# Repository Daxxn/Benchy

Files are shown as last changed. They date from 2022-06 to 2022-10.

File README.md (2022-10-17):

# BENCHY!!

Your electronics workbench buddy! (Is not actually your buddy, will probably try to kill you, and is hideously expensive.)

## REV1

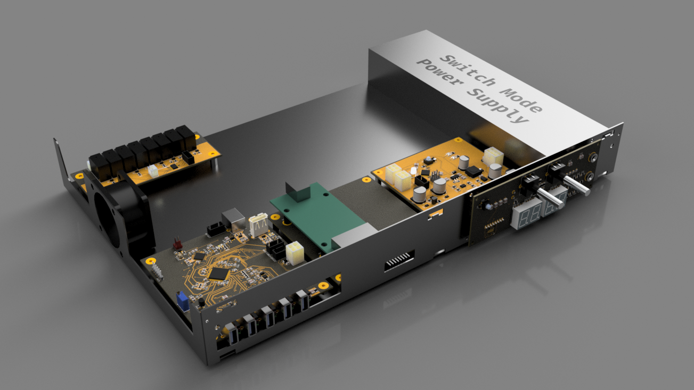
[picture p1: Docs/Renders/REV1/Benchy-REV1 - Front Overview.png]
REV1 Render


## REV2 - Work in Progress

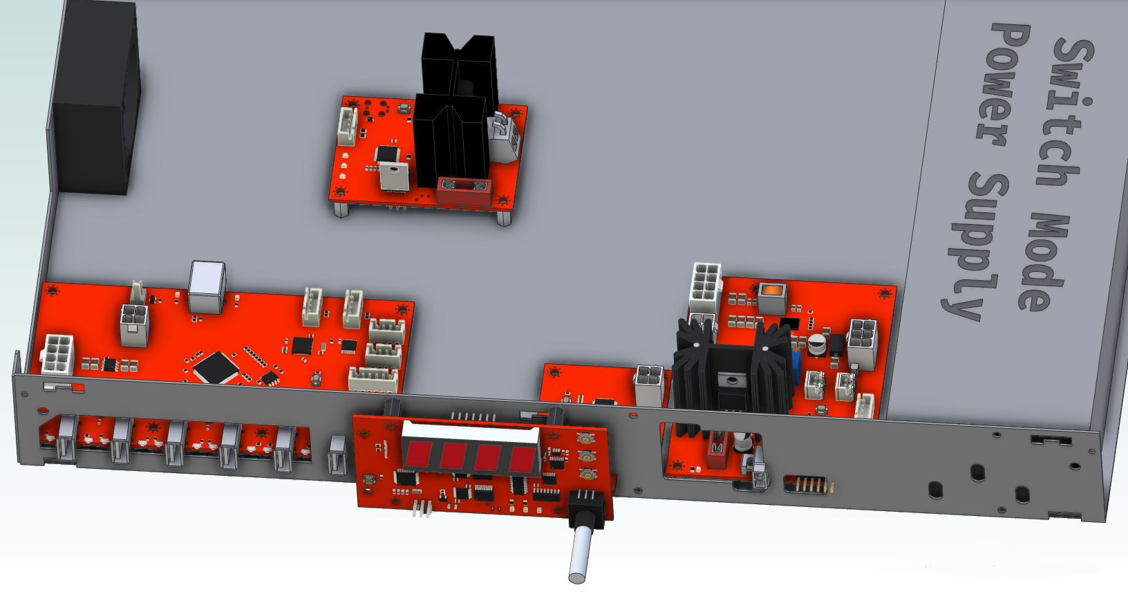
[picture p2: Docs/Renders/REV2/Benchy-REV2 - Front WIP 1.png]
REV2 Render


### Features

- 7 Port USB hub (2.0)
- All data ports are properly protected and able to report per-port current draw
- 5 power-only USB ports
- 8 Software controlled relays for general things like lighting
- Lab power supply capable of 10V @ 2A
- Voltage controlled 30V power supply with over-current protection
- Logic Analyzer
- Electronic load able to sink 5A
- LCR Meter

## I2C Bus

Im using a quite extensive I2C bus system to communicate with the different boards and functional blocks. This cuts WAY down on the number of wires and pins required for the main controller and allows for better modularity within benchy.

Due to the size of the bus and the different devices, the bus is split by an I2C Mux to keep bus integrity while communicating to far PCBs.

## USB Hub

The main reason why I needed to design my own USB hub instead of stuffing an off the shelf hub benchys trumpet was the absolute lack of protection circuitry in most "consumer grade" USB hubs. Theres no back-feed protection, verry little to no current monitoring, and the bare minimum ESD and EMI protection. Thats just not acceptable! imagine my supprise when I cracked open a $85 hub and found a couple controllers and thats it. The cost of finding a hub that has these protections is going to be around the same price as designing and building my own. (Except for the time investment...) Also, these features arent exaclty flashy, they dont look very good on a brochure. So they usually arent there.

The most frustrating part is that these manufacturers _claim_ to conform to the USB spec when the lack protections doesnt.

## Power Supply

The one thing that made the two different power supplies possible was the Switch-Mode Power Supply (SMPS) that was built into the DVR box that spawned this project. The output from the SMPS is a high-current 12V source and a 30V source.

### Adjustable supply

- 30v @ 2A
- Controlled over USB or front panel

The adjustable supply is built with help from [Dave, (Thanks Dave!)](https://www.youtube.com/watch?v=CIGjActDeoM&list=PLBF35875F73B5C9B5&index=1&ab_channel=EEVblog) using the [LM317](https://rocelec.widen.net/view/pdf/mlzstqhekh/slvs044x.pdf?t.download=true&u=5oefqw) adjustable regulator.

### 5V Supply

The [SIC451](https://www.vishay.com/docs/77863/sic450_sic451_sic453.pdf) can supply 25 amps to the USB ports allowing each port to supply around 2 amps. Power is managed by the [UCS2114s.](https://ww1.microchip.com/downloads/aemDocuments/documents/APID/ProductDocuments/DataSheets/UCS2114-Data-Sheet-20005743B.pdf) Controlling both current limit and backfeeding.

## Electronic Load

Fairly standard design using a MOSFET in its linear region, dissipating alot of energy. With the help of a big heatsink and a fan, it can be used to load power supplies or other circuits. The current shunt will allow for precise measurement of power usage. Control is linked to the main microcontroller on the the main board. Allowing for USB control.

## Function generator

Creates sine, square, and triangle waves. from low (100Hz) to medium frequencies (100KHz).

## General Purpose Relays

8 channel relay block used to control general things around benchy.

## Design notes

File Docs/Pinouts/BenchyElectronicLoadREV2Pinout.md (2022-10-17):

# Benchy-ElectronicLoad-REV2

> > Micro: **NANO**
>
> > Digital Pins: **20**
> >
> > Analog Pins: **8**
>
> > Comms:
> > - UART
> > - SPI
> > - I2C

---

## Digital

### Set
Pin Count: 1

| Pin | Name | Type
| --- | --- | --- |
| 6 | I | OUT |

## Analog

### Sense
Pin Count: 2

| Pin | Name | Type
| --- | --- | --- |
| 1 | AI | IN |
| 2 | AV | IN |

## Serial

### UART

### Pins

| Name | Pin |
| --- | --- |
| TX | 1 |
| RX | 0 |

### SPI

### Pins

| Name | Pin |
| --- | --- |
| SCLK | 13 |
| MISO | 12 |
| MOSI | 11 |
| SS | 10 |

### I2C

### Pins

| Name | Pin |
| --- | --- |
| SCLK | 5 |
| SDA | 4 |

> Auto-generated by [PinGenerator app.](https://github.com/Daxxn/PinGenerator)
>
> Author: Daxxn

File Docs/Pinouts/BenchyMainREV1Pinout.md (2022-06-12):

# BenchyMainREV1

> > Micro: **PRO-MICRO**
>
> > Digital Pins: **16**
> >
> > Analog Pins: **4**
>
> > Comms:
> > - SPI
> > - I2C
> > - UART

---

## Digital

### PORT
Pin Count: 5

| Pin | Name | Type
| --- | --- | --- |
| 9 | EN_1 | IN |
| 6 | EN_2 | IN |
| 8 | EN_3 | IN |
| 10 | EN_4 | IN |
| 12 | EN_5 | IN |

### USB
Pin Count: 3

| Pin | Name | Type
| --- | --- | --- |
| 7 | RESET | IN |
| 11 | I2C_EN | IN |

### FAN
Pin Count: 1

| Pin | Name | Type
| --- | --- | --- |
| 13 | CTRL | IN |

## Analog

### PORT
Pin Count: 5

| Pin | Name | Type
| --- | --- | --- |
| 0 | ACURR_1 | IN |
| 1 | ACURR_2 | IN |
| 2 | ACURR_3 | IN |
| 3 | ACURR_4 | IN |
| 4 | ACURR_5 | IN |

### VBUS
Pin Count: 1

| Pin | Name | Type
| --- | --- | --- |
| 5 | ASENSE | IN |

## Serial

### SPI

### Pins

| Name | Pin |
| --- | --- |
| SCK | 15 |
| MISO | 14 |
| MOSI | 16 |

### I2C

### Pins

| Name | Pin |
| --- | --- |
| SDA | 2 |
| SCL | 3 |

### UART

### Pins

| Name | Pin |
| --- | --- |
| TX | 1 |
| RX | 0 |

> Auto-generated by [PinGenerator app.](https://github.com/Daxxn/PinGenerator)
>
> Author: Daxxn

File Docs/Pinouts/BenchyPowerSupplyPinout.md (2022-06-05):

# BenchyPowerSupply

> > Micro: **NANO**
>
> > Digital Pins: **20**
> >
> > Analog Pins: **8**
>
> > Comms:
> > - UART
> > - SPI
> > - I2C

---

## Digital

### Power
Pin Count: 4

| Pin | Name | Type
| --- | --- | --- |
| 2 | OC_SENSE_INT | IN |
| 3 | HIGH_PWM | PWM |
| 5 | LOW_VSET | PWM |
| 6 | LOW_ISET | PWM |

## Analog

### Power
Pin Count: 3

| Pin | Name | Type
| --- | --- | --- |
| 1 | AV30_SENSE | IN |
| 2 | AV12_SENSE | IN |
| 7 | AHIGH_CC_SENSE | IN |

## Serial

### UART

### Pins

| Name | Pin |
| --- | --- |
| TX | 1 |
| RX | 0 |

### SPI

### Pins

| Name | Pin |
| --- | --- |
| SCLK | 13 |
| MISO | 12 |
| MOSI | 11 |
| SS | 10 |

### I2C

### Pins

| Name | Pin |
| --- | --- |
| SCLK | 5 |
| SDA | 4 |

### Addresses

| Name | Pin |
| --- | --- |
| Front | 42 |

> Auto-generated by [PinGenerator app.](https://github.com/Daxxn/PinGenerator)
>
> Author: Daxxn

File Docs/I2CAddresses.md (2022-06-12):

# I2C Bus Addresses

## Main Controller / USB Hub

> Controller (Arduino PRO-MICRO) : MASTER
>
> Front Pannel (PCA9634) : 0x###

## Power Supply

> Controller : 0x11
>
> Front Pannel (Arduino NANO) : 0x12

## Electronic Load

> Controller : 0x21

## Function Generator / LCR Meter

> Controller (Arduino NANO) : 0x31
>
> Front Pannel (PCA9634) : 0x###
>
> LCR Meter (Arduino NANO) : 0x33

## Relays

> IO Expander (PCF8574) : 0x75

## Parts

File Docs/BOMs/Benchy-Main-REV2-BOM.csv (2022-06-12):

Part | Value | Device | Package | Description
C1 | 22pF | C_CHIP-0805(2012-METRIC) | CAPC2012X110 | Capacitor - Generic
C2 | 22pF | C_CHIP-0805(2012-METRIC) | CAPC2012X110 | Capacitor - Generic
C3 | 33pF | C_CHIP-0805(2012-METRIC) | CAPC2012X110 | Capacitor - Generic
C4 | 33pF | C_CHIP-0805(2012-METRIC) | CAPC2012X110 | Capacitor - Generic
C5 | 100nF | C_CHIP-1210(3225-METRIC) | CAPC3225X135 | Capacitor - Generic
C6 | 4.7uF | C_CHIP-0805(2012-METRIC) | CAPC2012X110 | Capacitor - Generic
C7 | 100nF | C_CHIP-0805(2012-METRIC) | CAPC2012X110 | Capacitor - Generic
C8 | 22pF | C_CHIP-0805(2012-METRIC) | CAPC2012X110 | Capacitor - Generic
C9 | 1uF | C_CHIP-0805(2012-METRIC) | CAPC2012X110 | Capacitor - Generic
C10 | 22pF | C_CHIP-0805(2012-METRIC) | CAPC2012X110 | Capacitor - Generic
C11 | 1uF | C_CHIP-0805(2012-METRIC) | CAPC2012X110 | Capacitor - Generic
C12 | 22pF | C_CHIP-0805(2012-METRIC) | CAPC2012X110 | Capacitor - Generic
C13 | 1uF | C_CHIP-0805(2012-METRIC) | CAPC2012X110 | Capacitor - Generic
C14 | 22pF | C_CHIP-0805(2012-METRIC) | CAPC2012X110 | Capacitor - Generic
C15 | 22pF | C_CHIP-0805(2012-METRIC) | CAPC2012X110 | Capacitor - Generic
C16 | 100nF | C_CHIP-0805(2012-METRIC) | CAPC2012X110 | Capacitor - Generic
C17 | 1uF | C_CHIP-0805(2012-METRIC) | CAPC2012X110 | Capacitor - Generic
C18 | 10uF | C_CHIP-0805(2012-METRIC) | CAPC2012X110 | Capacitor - Generic
C19 | 4.7uF | C_CHIP-0805(2012-METRIC) | CAPC2012X110 | Capacitor - Generic
C20 | 22pF | C_CHIP-0805(2012-METRIC) | CAPC2012X110 | Capacitor - Generic
C21 | 100nF | C_CHIP-0805(2012-METRIC) | CAPC2012X110 | Capacitor - Generic
C22 | 1uF | C_CHIP-0805(2012-METRIC) | CAPC2012X110 | Capacitor - Generic
C23 | 22pF | C_CHIP-0805(2012-METRIC) | CAPC2012X110 | Capacitor - Generic
C24 | 1uF | C_CHIP-0805(2012-METRIC) | CAPC2012X110 | Capacitor - Generic
C25 | 22pF | C_CHIP-0805(2012-METRIC) | CAPC2012X110 | Capacitor - Generic
C26 | 22pF | C_CHIP-0805(2012-METRIC) | CAPC2012X110 | Capacitor - Generic
C27 | 22pF | C_CHIP-0805(2012-METRIC) | CAPC2012X110 | Capacitor - Generic
C28 | 22pF | C_CHIP-0805(2012-METRIC) | CAPC2012X110 | Capacitor - Generic
C29 | 22pF | C_CHIP-0805(2012-METRIC) | CAPC2012X110 | Capacitor - Generic
C30 | 22pF | C_CHIP-0805(2012-METRIC) | CAPC2012X110 | Capacitor - Generic
C31 | 22pF | C_CHIP-0805(2012-METRIC) | CAPC2012X110 | Capacitor - Generic
C32 | 22pF | C_CHIP-0805(2012-METRIC) | CAPC2012X110 | Capacitor - Generic
C33 | 22pF | C_CHIP-0805(2012-METRIC) | CAPC2012X110 | Capacitor - Generic
C34 | 4.7uF | C_CHIP-0805(2012-METRIC) | CAPC2012X110 | Capacitor - Generic
C35 | 4.7uF | C_CHIP-0805(2012-METRIC) | CAPC2012X110 | Capacitor - Generic
C36 | 100nF | C_CHIP-0805(2012-METRIC) | CAPC2012X110 | Capacitor - Generic
C37 | 100nF | C_CHIP-0805(2012-METRIC) | CAPC2012X110 | Capacitor - Generic
C38 | 1uF | C_CHIP-0805(2012-METRIC) | CAPC2012X110 | Capacitor - Generic
C39 | 1uF | C_CHIP-0805(2012-METRIC) | CAPC2012X110 | Capacitor - Generic
C40 | 10uF | C_CHIP-0805(2012-METRIC) | CAPC2012X110 | Capacitor - Generic
C41 | 10uF | C_CHIP-0805(2012-METRIC) | CAPC2012X110 | Capacitor - Generic
C42 | 100nF | C_CHIP-0805(2012-METRIC) | CAPC2012X110 | Capacitor - Generic
C43 | 100nF | C_CHIP-0805(2012-METRIC) | CAPC2012X110 | Capacitor - Generic
C44 | 1uF | C_CHIP-1210(3225-METRIC) | CAPC3225X135 | Capacitor - Generic
C46 | 100nF | C_CHIP-1210(3225-METRIC) | CAPC3225X135 | Capacitor - Generic
C47 | 2.2uF | C_CHIP-1210(3225-METRIC) | CAPC3225X135 | Capacitor - Generic
C48 | 1uF | C_CHIP-1210(3225-METRIC) | CAPC3225X135 | Capacitor - Generic
C49 | 1uF | C_CHIP-1210(3225-METRIC) | CAPC3225X135 | Capacitor - Generic
C50 | 120uF | C-POL_TANTALUM-2917(7343-METRIC) | CAPMP7343X310N | Capacitor Polarised - Generic
C51 | 120uF | C-POL_TANTALUM-2917(7343-METRIC) | CAPMP7343X310N | Capacitor Polarised - Generic
C52 | 120uF | C-POL_TANTALUM-2917(7343-METRIC) | CAPMP7343X310N | Capacitor Polarised - Generic
C53 | 120uF | C-POL_TANTALUM-2917(7343-METRIC) | CAPMP7343X310N | Capacitor Polarised - Generic
C54 | 120uF | C-POL_TANTALUM-2917(7343-METRIC) | CAPMP7343X310N | Capacitor Polarised - Generic
C55 | 120uF | C-POL_TANTALUM-2917(7343-METRIC) | CAPMP7343X310N | Capacitor Polarised - Generic
C56 | 100nF | C_CHIP-0805(2012-METRIC) | CAPC2012X110 | Capacitor - Generic
C57 | 100nF | C_CHIP-0805(2012-METRIC) | CAPC2012X110 | Capacitor - Generic
C58 | 1uF | C_CHIP-0805(2012-METRIC) | CAPC2012X110 | Capacitor - Generic
C59 | 100nF | C_CHIP-1210(3225-METRIC) | CAPC3225X135 | Capacitor - Generic
D1 | 1N4448WS | 1N4448WS | SOD2412X120N | Small Signal Diode
D2 | 1N4448WS | 1N4448WS | SOD2412X120N | Small Signal Diode
D3 | 1N4448WS | 1N4448WS | SOD2412X120N | Small Signal Diode
D4 | 1N4448WS | 1N4448WS | SOD2412X120N | Small Signal Diode
D5 | 1N4448WS | 1N4448WS | SOD2412X120N | Small Signal Diode
D6 | GREEN | CHIP-ROUND-G_0805 | LEDC2012X105N_RND-G
D7 | GREEN | CHIP-ROUND-G_0805 | LEDC2012X105N_RND-G
D8 | WP4060VH/IGD | WP4060VH/IGD | WP4060VH
D9 | WP4060VH/IGD | WP4060VH/IGD | WP4060VH
D10 | WP4060VH/IGD | WP4060VH/IGD | WP4060VH
D11 | WP4060VH/IGD | WP4060VH/IGD | WP4060VH
D12 | WP4060VH/IGD | WP4060VH/IGD | WP4060VH
D13 | SS14-CHAN | SS14-CHAN | SS14-CHAN | SMD Schottky
D15 | YELLOW | CHIP-ROUND-Y_0805 | LEDC2012X105N_RND-Y
D16 | YELLOW | CHIP-ROUND-Y_0805 | LEDC2012X105N_RND-Y
ICSP | PINHD-1X6 | PINHD-1X6 | 1X06 | PIN HEADER
J-FRONT-COM | 690367290476 | 690367290476 | 690367290476
J-FUNC-COM | B4B-XH-A | B4B-XH-A | JST-XH-4
J-LOGA-USB | 1734366 | 1734366 | 1734366 | USB(2.0) Type-A, RCPT, 4POS, THT-VERT
J-PS-COM | B4B-XH-A | B4B-XH-A | JST-XH-4
J-RELAY-COM | B4B-XH-A | B4B-XH-A | JST-XH-4
J-USB-OUT | USB-B1HSB6 | USB-B1HSB6 | USB-B1HSB6
J1 | 640456-2 | 640456-2 | 640456-2
J2 | MOLEX-4 | MOLEX-4 | MOLEX-4
L1 | 4.7uH | L_CHIP-1206(3216-METRIC) | INDC3216X190 | Inductor Fixed - Generic
MP1 | STANDOFF_F/F_M2.5_5MM | STANDOFF_F/F_M2.5_5MM | STANDOFF_HEX_FEMALE_500X500_M2.5X0.45_MTGP755H270 | Female-Female Standoff/Spacer with Mounting pad and hole.
MP2 | STANDOFF_F/F_M2.5_5MM | STANDOFF_F/F_M2.5_5MM | STANDOFF_HEX_FEMALE_500X500_M2.5X0.45_MTGP755H270 | Female-Female Standoff/Spacer with Mounting pad and hole.
MP3 | STANDOFF_F/F_M2.5_5MM | STANDOFF_F/F_M2.5_5MM | STANDOFF_HEX_FEMALE_500X500_M2.5X0.45_MTGP755H270 | Female-Female Standoff/Spacer with Mounting pad and hole.
MP4 | STANDOFF_F/F_M2.5_5MM | STANDOFF_F/F_M2.5_5MM | STANDOFF_HEX_FEMALE_500X500_M2.5X0.45_MTGP755H270 | Female-Female Standoff/Spacer with Mounting pad and hole.
P2 | 50KΩ | 3296W | 3296W
Q1 | SQ2310ES | SQ2310ES | SOT-23-3_-_SOT95P280X100-3N | N-Ch MOSFET
Q2 | CPH3348-TL-W | CPH3348-TL-W | SOT-23-3_-_SOT95P280X100-3N | -12V P-Ch MOSFET
Q3 | CPH3348-TL-W | CPH3348-TL-W | SOT-23-3_-_SOT95P280X100-3N | -12V P-Ch MOSFET
Q4 | BC807 | BC807 | SOT-23-3_-_SOT95P280X100-3N | PNP 45V Transistor
Q5 | BC807 | BC807 | SOT-23-3_-_SOT95P280X100-3N | PNP 45V Transistor
Q6 | BC807 | BC807 | SOT-23-3_-_SOT95P280X100-3N | PNP 45V Transistor
Q7 | BC807 | BC807 | SOT-23-3_-_SOT95P280X100-3N | PNP 45V Transistor
Q8 | CPH3348-TL-W | CPH3348-TL-W | SOT-23-3_-_SOT95P280X100-3N | -12V P-Ch MOSFET
Q9 | BC807 | BC807 | SOT-23-3_-_SOT95P280X100-3N | PNP 45V Transistor
Q10 | BC807 | BC807 | SOT-23-3_-_SOT95P280X100-3N | PNP 45V Transistor
Q11 | CPH3348-TL-W | CPH3348-TL-W | SOT-23-3_-_SOT95P280X100-3N | -12V P-Ch MOSFET
Q12 | BC807 | BC807 | SOT-23-3_-_SOT95P280X100-3N | PNP 45V Transistor
Q13 | BC807 | BC807 | SOT-23-3_-_SOT95P280X100-3N | PNP 45V Transistor
Q14 | CPH3348-TL-W | CPH3348-TL-W | SOT-23-3_-_SOT95P280X100-3N | -12V P-Ch MOSFET
Q15 | BC807 | BC807 | SOT-23-3_-_SOT95P280X100-3N | PNP 45V Transistor
Q16 | BC807 | BC807 | SOT-23-3_-_SOT95P280X100-3N | PNP 45V Transistor
Q17 | DMG2301L | DMG2301L | SOT-23-3_-_SOT95P280X100-3N
Q18 | DMG2301L | DMG2301L | SOT-23-3_-_SOT95P280X100-3N
Q19 | DMG2301L | DMG2301L | SOT-23-3_-_SOT95P280X100-3N
Q20 | DMG2301L | DMG2301L | SOT-23-3_-_SOT95P280X100-3N
Q21 | DMG2301L | DMG2301L | SOT-23-3_-_SOT95P280X100-3N
R1 | 100Ω | R-US_CHIP-0805(2012-METRIC) | RESC2012X65 | Resistor Fixed - ANSI
R2 | 10KΩ | R-US_CHIP-0805(2012-METRIC) | RESC2012X65 | Resistor Fixed - ANSI
R3 | 100KΩ | R-US_CHIP-1206(3216-METRIC) | RESC3216X70 | Resistor Fixed - ANSI
R4 | 100KΩ | R-US_CHIP-1206(3216-METRIC) | RESC3216X70 | Resistor Fixed - ANSI
R5 | 100KΩ | R-US_CHIP-1206(3216-METRIC) | RESC3216X70 | Resistor Fixed - ANSI
R6 | 100KΩ | R-US_CHIP-1206(3216-METRIC) | RESC3216X70 | Resistor Fixed - ANSI
R7 | 100KΩ | R-US_CHIP-1206(3216-METRIC) | RESC3216X70 | Resistor Fixed - ANSI
R8 | 100KΩ | R-US_CHIP-1206(3216-METRIC) | RESC3216X70 | Resistor Fixed - ANSI
R9 | 100KΩ | R-US_CHIP-1206(3216-METRIC) | RESC3216X70 | Resistor Fixed - ANSI
R10 | 100KΩ | R-US_CHIP-1206(3216-METRIC) | RESC3216X70 | Resistor Fixed - ANSI
R11 | 10KΩ | R-US_CHIP-1206(3216-METRIC) | RESC3216X70 | Resistor Fixed - ANSI
R12 | 100KΩ | R-US_CHIP-1206(3216-METRIC) | RESC3216X70 | Resistor Fixed - ANSI
R13 | 100KΩ | R-US_CHIP-1206(3216-METRIC) | RESC3216X70 | Resistor Fixed - ANSI
R14 | 150mΩ | R-US_CHIP-2010(5025-METRIC) | RESC5025X71 | Resistor Fixed - ANSI
R15 | 150mΩ | R-US_CHIP-2010(5025-METRIC) | RESC5025X71 | Resistor Fixed - ANSI
R16 | 150mΩ | R-US_CHIP-2010(5025-METRIC) | RESC5025X71 | Resistor Fixed - ANSI
R17 | 150mΩ | R-US_CHIP-2010(5025-METRIC) | RESC5025X71 | Resistor Fixed - ANSI
R18 | 150mΩ | R-US_CHIP-2010(5025-METRIC) | RESC5025X71 | Resistor Fixed - ANSI
R19 | 27Ω | R-US_CHIP-0805(2012-METRIC) | RESC2012X65 | Resistor Fixed - ANSI
R20 | 27Ω | R-US_CHIP-0805(2012-METRIC) | RESC2012X65 | Resistor Fixed - ANSI
R21 | 27Ω | R-US_CHIP-0805(2012-METRIC) | RESC2012X65 | Resistor Fixed - ANSI
R22 | 27Ω | R-US_CHIP-0805(2012-METRIC) | RESC2012X65 | Resistor Fixed - ANSI
R23 | 27Ω | R-US_CHIP-0805(2012-METRIC) | RESC2012X65 | Resistor Fixed - ANSI
R24 | 27Ω | R-US_CHIP-0805(2012-METRIC) | RESC2012X65 | Resistor Fixed - ANSI
R25 | 1MΩ | R-US_CHIP-0805(2012-METRIC) | RESC2012X65 | Resistor Fixed - ANSI
R26 | 10KΩ | R-US_CHIP-0805(2012-METRIC) | RESC2012X65 | Resistor Fixed - ANSI
R27 | 100KΩ | R-US_CHIP-0805(2012-METRIC) | RESC2012X65 | Resistor Fixed - ANSI
R28 | 100Ω | R-US_CHIP-0805(2012-METRIC) | RESC2012X65 | Resistor Fixed - ANSI
R29 | 100Ω | R-US_CHIP-0805(2012-METRIC) | RESC2012X65 | Resistor Fixed - ANSI
R30 | 100Ω | R-US_CHIP-0805(2012-METRIC) | RESC2012X65 | Resistor Fixed - ANSI
R31 | 100Ω | R-US_CHIP-0805(2012-METRIC) | RESC2012X65 | Resistor Fixed - ANSI
R32 | 100Ω | R-US_CHIP-0805(2012-METRIC) | RESC2012X65 | Resistor Fixed - ANSI
R33 | 10KΩ | R-US_CHIP-0805(2012-METRIC) | RESC2012X65 | Resistor Fixed - ANSI
R34 | 10KΩ | R-US_CHIP-0805(2012-METRIC) | RESC2012X65 | Resistor Fixed - ANSI
R35 | 10KΩ | R-US_CHIP-0805(2012-METRIC) | RESC2012X65 | Resistor Fixed - ANSI
R36 | 10KΩ | R-US_CHIP-0805(2012-METRIC) | RESC2012X65 | Resistor Fixed - ANSI
R37 | 10KΩ | R-US_CHIP-0805(2012-METRIC) | RESC2012X65 | Resistor Fixed - ANSI
R38 | 27Ω | R-US_CHIP-0805(2012-METRIC) | RESC2012X65 | Resistor Fixed - ANSI
R39 | 27Ω | R-US_CHIP-0805(2012-METRIC) | RESC2012X65 | Resistor Fixed - ANSI
R40 | 27Ω | R-US_CHIP-0805(2012-METRIC) | RESC2012X65 | Resistor Fixed - ANSI
R41 | 27Ω | R-US_CHIP-0805(2012-METRIC) | RESC2012X65 | Resistor Fixed - ANSI
R42 | 27Ω | R-US_CHIP-0805(2012-METRIC) | RESC2012X65 | Resistor Fixed - ANSI
R43 | 27Ω | R-US_CHIP-0805(2012-METRIC) | RESC2012X65 | Resistor Fixed - ANSI
R44 | 27Ω | R-US_CHIP-0805(2012-METRIC) | RESC2012X65 | Resistor Fixed - ANSI
R45 | 27Ω | R-US_CHIP-0805(2012-METRIC) | RESC2012X65 | Resistor Fixed - ANSI
R46 | 27Ω | R-US_CHIP-0805(2012-METRIC) | RESC2012X65 | Resistor Fixed - ANSI
R47 | 27Ω | R-US_CHIP-0805(2012-METRIC) | RESC2012X65 | Resistor Fixed - ANSI
R48 | 15KΩ | R-US_CHIP-0805(2012-METRIC) | RESC2012X65 | Resistor Fixed - ANSI
R49 | 15KΩ | R-US_CHIP-0805(2012-METRIC) | RESC2012X65 | Resistor Fixed - ANSI
R50 | 15KΩ | R-US_CHIP-0805(2012-METRIC) | RESC2012X65 | Resistor Fixed - ANSI
R51 | 15KΩ | R-US_CHIP-0805(2012-METRIC) | RESC2012X65 | Resistor Fixed - ANSI
R52 | 15KΩ | R-US_CHIP-0805(2012-METRIC) | RESC2012X65 | Resistor Fixed - ANSI
R53 | 15KΩ | R-US_CHIP-0805(2012-METRIC) | RESC2012X65 | Resistor Fixed - ANSI
R54 | 15KΩ | R-US_CHIP-0805(2012-METRIC) | RESC2012X65 | Resistor Fixed - ANSI
R55 | 15KΩ | R-US_CHIP-0805(2012-METRIC) | RESC2012X65 | Resistor Fixed - ANSI
R56 | 15KΩ | R-US_CHIP-0805(2012-METRIC) | RESC2012X65 | Resistor Fixed - ANSI
R57 | 15KΩ | R-US_CHIP-0805(2012-METRIC) | RESC2012X65 | Resistor Fixed - ANSI
R58 | 15KΩ | R-US_CHIP-0805(2012-METRIC) | RESC2012X65 | Resistor Fixed - ANSI
R59 | 15KΩ | R-US_CHIP-0805(2012-METRIC) | RESC2012X65 | Resistor Fixed - ANSI
R60 | 15KΩ | R-US_CHIP-0805(2012-METRIC) | RESC2012X65 | Resistor Fixed - ANSI
R61 | 15KΩ | R-US_CHIP-0805(2012-METRIC) | RESC2012X65 | Resistor Fixed - ANSI
R62 | 15KΩ | R-US_CHIP-0805(2012-METRIC) | RESC2012X65 | Resistor Fixed - ANSI
R63 | 15KΩ | R-US_CHIP-0805(2012-METRIC) | RESC2012X65 | Resistor Fixed - ANSI
R64 | 4.7KΩ | R-US_CHIP-0805(2012-METRIC) | RESC2012X65 | Resistor Fixed - ANSI
R65 | 4.7KΩ | R-US_CHIP-0805(2012-METRIC) | RESC2012X65 | Resistor Fixed - ANSI
R66 | 12KΩ | R-US_CHIP-0805(2012-METRIC) | RESC2012X65 | Resistor Fixed - ANSI
R67 | 330Ω | R-US_CHIP-0805(2012-METRIC) | RESC2012X65 | Resistor Fixed - ANSI
R68 | 330Ω | R-US_CHIP-0805(2012-METRIC) | RESC2012X65 | Resistor Fixed - ANSI
R69 | 330Ω | R-US_CHIP-0805(2012-METRIC) | RESC2012X65 | Resistor Fixed - ANSI
R70 | 330Ω | R-US_CHIP-0805(2012-METRIC) | RESC2012X65 | Resistor Fixed - ANSI
R71 | 330Ω | R-US_CHIP-0805(2012-METRIC) | RESC2012X65 | Resistor Fixed - ANSI
R72 | 330Ω | R-US_CHIP-0805(2012-METRIC) | RESC2012X65 | Resistor Fixed - ANSI
R73 | 330Ω | R-US_CHIP-0805(2012-METRIC) | RESC2012X65 | Resistor Fixed - ANSI
R74 | 330Ω | R-US_CHIP-0805(2012-METRIC) | RESC2012X65 | Resistor Fixed - ANSI
R75 | 330Ω | R-US_CHIP-0805(2012-METRIC) | RESC2012X65 | Resistor Fixed - ANSI
R76 | 330Ω | R-US_CHIP-0805(2012-METRIC) | RESC2012X65 | Resistor Fixed - ANSI
R77 | 10KΩ | R-US_CHIP-0805(2012-METRIC) | RESC2012X65 | Resistor Fixed - ANSI
R78 | 10KΩ | R-US_CHIP-0805(2012-METRIC) | RESC2012X65 | Resistor Fixed - ANSI
R79 | 100KΩ | R-US_CHIP-0805(2012-METRIC) | RESC2012X65 | Resistor Fixed - ANSI
R80 | 330Ω | R-US_CHIP-0805(2012-METRIC) | RESC2012X65 | Resistor Fixed - ANSI
R81 | 330Ω | R-US_CHIP-0805(2012-METRIC) | RESC2012X65 | Resistor Fixed - ANSI
R82 | 1KΩ | R-US_CHIP-0805(2012-METRIC) | RESC2012X65 | Resistor Fixed - ANSI
R83 | 3.3KΩ | R-US_CHIP-0805(2012-METRIC) | RESC2012X65 | Resistor Fixed - ANSI
R84 | 1KΩ | R-US_CHIP-0805(2012-METRIC) | RESC2012X65 | Resistor Fixed - ANSI
R85 | 1KΩ | R-US_CHIP-0805(2012-METRIC) | RESC2012X65 | Resistor Fixed - ANSI
R86 | 1KΩ | R-US_CHIP-0805(2012-METRIC) | RESC2012X65 | Resistor Fixed - ANSI
R87 | 1KΩ | R-US_CHIP-0805(2012-METRIC) | RESC2012X65 | Resistor Fixed - ANSI
R88 | 1KΩ | R-US_CHIP-0805(2012-METRIC) | RESC2012X65 | Resistor Fixed - ANSI
R89 | 1KΩ | R-US_CHIP-0805(2012-METRIC) | RESC2012X65 | Resistor Fixed - ANSI
R90 | 330Ω | R-US_CHIP-0805(2012-METRIC) | RESC2012X65 | Resistor Fixed - ANSI
R91 | 330Ω | R-US_CHIP-0805(2012-METRIC) | RESC2012X65 | Resistor Fixed - ANSI
R92 | 330Ω | R-US_CHIP-1206(3216-METRIC) | RESC3216X70 | Resistor Fixed - ANSI
R93 | 100KΩ | R-US_CHIP-0805(2012-METRIC) | RESC2012X65 | Resistor Fixed - ANSI
R94 | 1.5KΩ | R-US_CHIP-0805(2012-METRIC) | RESC2012X65 | Resistor Fixed - ANSI
R95 | 1.5KΩ | R-US_CHIP-0805(2012-METRIC) | RESC2012X65 | Resistor Fixed - ANSI
R96 | 1.5KΩ | R-US_CHIP-0805(2012-METRIC) | RESC2012X65 | Resistor Fixed - ANSI
R97 | 1.5KΩ | R-US_CHIP-0805(2012-METRIC) | RESC2012X65 | Resistor Fixed - ANSI
R98 | 1.5KΩ | R-US_CHIP-0805(2012-METRIC) | RESC2012X65 | Resistor Fixed - ANSI
R99 | 50KΩ | R-US_CHIP-0805(2012-METRIC) | RESC2012X65 | Resistor Fixed - ANSI
R100 | 50KΩ | R-US_CHIP-0805(2012-METRIC) | RESC2012X65 | Resistor Fixed - ANSI
RESET | TL3365 | TL3365 | TL3365
RV1 | VC1206 | VARISTOR_VC1206_CHIP-1206 | VARC3216X102N | Varistor - Popular parts
RV2 | VC1206 | VARISTOR_VC1206_CHIP-1206 | VARC3216X102N | Varistor - Popular parts
RV3 | VC1206 | VARISTOR_VC1206_CHIP-1206 | VARC3216X102N | Varistor - Popular parts
RV4 | VC1206 | VARISTOR_VC1206_CHIP-1206 | VARC3216X102N | Varistor - Popular parts
RV5 | VC1206 | VARISTOR_VC1206_CHIP-1206 | VARC3216X102N | Varistor - Popular parts
TVS1 | D5V0L2B3SO | D5V0L2B3SO | SOT23-3_-_SOT95P240X110-3N
TVS3 | D5V0L2B3SO | D5V0L2B3SO | SOT23-3_-_SOT95P240X110-3N
TVS4 | D5V0L2B3SO | D5V0L2B3SO | SOT23-3_-_SOT95P240X110-3N
TVS6 | D5V0L2B3SO | D5V0L2B3SO | SOT23-3_-_SOT95P240X110-3N
TVS8 | D5V0L2B3SO | D5V0L2B3SO | SOT23-3_-_SOT95P240X110-3N
TVS10 | D5V0L2B3SO | D5V0L2B3SO | SOT23-3_-_SOT95P240X110-3N
TVS12 | D5V0L2B3SO | D5V0L2B3SO | SOT23-3_-_SOT95P240X110-3N
U1 | INA4180A4IPWRHS-TSSOP-14 | INA4180A4IPWRHS-TSSOP-14 | HS-TSSOP-14 | 4 Ch Current Shunt Amplifier
U2 | INA181A-X | INA181A-X | SOT-23-6PIN | Single Current Shunt Amplifier
U3 | ATMEGA-32U4 | ATMEGA-32U4 | QFN-44_-_QFN50P700X700X100-45T500N | Stand Alone - Ardunio Pro Micro
U4 | USB2507 | USB2507 | TQFP-80_-_QFP50P1400X1400X120-80N | USB 2.0 7-Port Hub Controller
U6 | PCA9515HS-SO-8 | PCA9515HS-SO-8 | SOIC127P600X175-8N__HS__AS5600 | I2C Bus Repeater
U7 | 24CXXSOIC-8 | 24CXXSOIC-8 | SOIC127P600X175-8N__AS5600
U8 | TSX339-HS-TSSOP-14 | TSX339-HS-TSSOP-14 | TSSOP-14-HS_-_SOP65P640X120-14N | sub {
U12 | TLV7021-SOT23-5 | TLV7021-SOT23-5 | SOT23-5_-_SOT95P280X145-5N | sub {
U13 | SN74LV08 | SN74LV08 | SOIC-14_-_SOIC127P600X175-14N | Quad AND Gates 2-Input
U15 | CD4011 | CD4011 | TSSOP-14_-_SOP65P640X120-14N | Quad NAND Gates 2-Input
U17 | TLV9151-HS | TLV9151-HS | SOT23-5-HS_-_SOT95P280X145-5N | sub {
U19 | 74HC2G08 | 74HC2G08 | TSSOP-8_-_SOP65P400X110-8N | Dual AND Gates 2-Input
U20 | SN74LVC1G06 | SN74LVC1G06 | SOT23-5_-_SOT95P275X145-5N
USB-1 | USB-A-SIDE | USB-A-SIDE | USB-A-SIDE
USB-2 | USB-A-SIDE | USB-A-SIDE | USB-A-SIDE
USB-3 | USB-A-SIDE | USB-A-SIDE | USB-A-SIDE
USB-4 | USB-A-SIDE | USB-A-SIDE | USB-A-SIDE
USB-5 | USB-A-SIDE | USB-A-SIDE | USB-A-SIDE
VR1 | TL1431TO-92 | TL1431TO-92 | TO-92 | Precision Adjustable Voltage Reference
X1 | ECS-240-10-37B2-JTN | ECS-240-10-37B2-JTN | SMD-OSC-2X1_6_-_OSCCC200X160X50N | 2X1.6 Crystal Oscillator
X4 | 16MHz | RH100-16-8-1010 | OSC-1010_-_OSCCC320X250X69N | Crystal Oscillator SMD

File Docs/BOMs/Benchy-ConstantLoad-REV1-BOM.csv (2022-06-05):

Part | Value | Device | Package | Description
C1 | 100nF | C_CHIP-0805(2012-METRIC) | CAPC2012X110 | Capacitor - Generic
C2 | 100nF | C_CHIP-0805(2012-METRIC) | CAPC2012X110 | Capacitor - Generic
C3 | 100nF | C_CHIP-0805(2012-METRIC) | CAPC2012X110 | Capacitor - Generic
C4 | 100nF | C_CHIP-0805(2012-METRIC) | CAPC2012X110 | Capacitor - Generic
C5 | 100nF | C_CHIP-0805(2012-METRIC) | CAPC2012X110 | Capacitor - Generic
C6 | 1uF | C_CHIP-0805(2012-METRIC) | CAPC2012X110 | Capacitor - Generic
C7 | 100nF | C_CHIP-0805(2012-METRIC) | CAPC2012X110 | Capacitor - Generic
C8 | 47uF | C_CHIP-0805(2012-METRIC) | CAPC2012X110 | Capacitor - Generic
C9 | 100nF | C_CHIP-0805(2012-METRIC) | CAPC2012X110 | Capacitor - Generic
C10 | 100nF | C_CHIP-0805(2012-METRIC) | CAPC2012X110 | Capacitor - Generic
C11 | 100nF | C_CHIP-0805(2012-METRIC) | CAPC2012X110 | Capacitor - Generic
D1 | LSM115JE3 | LSM115JE3 | DO-214BA_-_DIOM4336X330N | sub {
ICSP1 | ICSP-TAG-CONN | ICSP-TAG-CONN | TAG-CONN
J-FRONT-COM | B4B-XH-A-REV2 | B4B-XH-A-REV2 | JST-XH-4
J-MAIN-COM | B4B-XH-A-REV2 | B4B-XH-A-REV2 | JST-XH-4
J-PWR | B2B-XH-A-REV2 | B2B-XH-A-REV2 | JST-XH-2
J1 | 2834082-1 | 2834082-1 | 2834082-1
MP1 | STANDOFF_F/F_M3_10MM | STANDOFF_F/F_M3_10MM | STANDOFF_HEX_FEMALE_550X1000_M3X0.5_MTGP850H320 | Female-Female Standoff/Spacer with Mounting pad and hole.
MP2 | STANDOFF_F/F_M3_10MM | STANDOFF_F/F_M3_10MM | STANDOFF_HEX_FEMALE_550X1000_M3X0.5_MTGP850H320 | Female-Female Standoff/Spacer with Mounting pad and hole.
MP3 | STANDOFF_F/F_M3_10MM | STANDOFF_F/F_M3_10MM | STANDOFF_HEX_FEMALE_550X1000_M3X0.5_MTGP850H320 | Female-Female Standoff/Spacer with Mounting pad and hole.
MP4 | STANDOFF_F/F_M3_10MM | STANDOFF_F/F_M3_10MM | STANDOFF_HEX_FEMALE_550X1000_M3X0.5_MTGP850H320 | Female-Female Standoff/Spacer with Mounting pad and hole.
P1 | 10K | 3296W | 3296W
Q2 | IRF840-HSHS | IRF840-HSHS | TO-220-VERT-HS | sub {
R1 | 10K | R-US_CHIP-0805(2012-METRIC) | RESC2012X65 | Resistor Fixed - ANSI
R2 | 10K | R-US_CHIP-0805(2012-METRIC) | RESC2012X65 | Resistor Fixed - ANSI
R3 | 10 | R-US_CHIP-0805(2012-METRIC) | RESC2012X65 | Resistor Fixed - ANSI
R4 | 1K | R-US_CHIP-0805(2012-METRIC) | RESC2012X65 | Resistor Fixed - ANSI
R5 | 4.7k | R-US_CHIP-0805(2012-METRIC) | RESC2012X65 | Resistor Fixed - ANSI
R6 | 4.7k | R-US_CHIP-0805(2012-METRIC) | RESC2012X65 | Resistor Fixed - ANSI
R7 | 4.7K | R-US_CHIP-0805(2012-METRIC) | RESC2012X65 | Resistor Fixed - ANSI
R8 | 10K | R-US_CHIP-0805(2012-METRIC) | RESC2012X65 | Resistor Fixed - ANSI
R9 | 10K | R-US_CHIP-0805(2012-METRIC) | RESC2012X65 | Resistor Fixed - ANSI
RESET | TL3365 | TL3365 | TL3365
RS1 | 14AFR010E | 14AFR010E | RESAD2182W66L1845D630B | High Power Shunt Resistor
U1 | ATMEGA-328PHS | ATMEGA-328PHS | QFP-32-HS_-_QFP80P900X900X120-33T500N | Stand Alone - Arduino Nano
U2 | ZXGD3009E6NORM | ZXGD3009E6NORM | SOT-23-6PIN
U3 | INA181A-X | INA181A-X | SOT-23-6PIN | Single Current Shunt Amplifier
U4 | TLV7021-SOT23-5 | TLV7021-SOT23-5 | SOT23-5_-_SOT95P280X145-5N | Low Power 5V Comparator
X1 | CSTCE16M0V53-R0SMD | CSTCE16M0V53-R0SMD | CSTCE16M0V53-R0 | SMD Resonator from the Arduino NANO

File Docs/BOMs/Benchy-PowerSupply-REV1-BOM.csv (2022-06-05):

Part | Value | Device | Package | Description
C1 | 100uF | C-POL_ECAP-10.5MM | CAPAE1030X1050N | Capacitor Polarised - Generic
C2 | 100nF | C_CHIP-0805(2012-METRIC) | CAPC2012X110 | Capacitor - Generic
C3 | 10uF | C_CHIP-1210(3225-METRIC) | CAPC3225X135 | Capacitor - Generic
C4 | 0.1uF | C_CHIP-1210(3225-METRIC) | CAPC3225X135 | Capacitor - Generic
C5 | 4.7nF | C_CHIP-1210(3225-METRIC) | CAPC3225X135 | Capacitor - Generic
C6 | 0.1uF | C_CHIP-1210(3225-METRIC) | CAPC3225X135 | Capacitor - Generic
C7 | 10uF | C_CHIP-1210(3225-METRIC) | CAPC3225X135 | Capacitor - Generic
C8 | 100uF | C-POL_ECAP-8.5MM | CAPAE830X1050N | Capacitor Polarised - Generic
C9 | 100nF | C_CHIP-1206(3216-METRIC) | CAPC3216X135 | Capacitor - Generic
C10 | 10uF | C-POL_TANTALUM-1206(3216-METRIC) | CAPMP3216X180N | Capacitor Polarised - Generic
C11 | 1uF | C_CHIP-1210(3225-METRIC) | CAPC3225X135 | Capacitor - Generic
C12 | 0.1uF | C_CHIP-1210(3225-METRIC) | CAPC3225X135 | Capacitor - Generic
C13 | 10uF | C_CHIP-1210(3225-METRIC) | CAPC3225X135 | Capacitor - Generic
C14 | 4.7uF | C_CHIP-1210(3225-METRIC) | CAPC3225X135 | Capacitor - Generic
C15 | 4.7uF | C_CHIP-1210(3225-METRIC) | CAPC3225X135 | Capacitor - Generic
C16 | 100nF | C_CHIP-0805(2012-METRIC) | CAPC2012X110 | Capacitor - Generic
C17 | 22nF | C_CHIP-1210(3225-METRIC) | CAPC3225X135 | Capacitor - Generic
C18 | 22nF | C_CHIP-1210(3225-METRIC) | CAPC3225X135 | Capacitor - Generic
C19 | 100nF | C_CHIP-1210(3225-METRIC) | CAPC3225X135 | Capacitor - Generic
C20 | 1uF | C_CHIP-1210(3225-METRIC) | CAPC3225X135 | Capacitor - Generic
C21 | 1uF | C_CHIP-1210(3225-METRIC) | CAPC3225X135 | Capacitor - Generic
C22 | 100nF | C_CHIP-1210(3225-METRIC) | CAPC3225X135 | Capacitor - Generic
C23 | 47uF | C-POL_TANTALUM-1206(3216-METRIC) | CAPMP3216X180N | Capacitor Polarised - Generic
C24 | 22nF | C_CHIP-1210(3225-METRIC) | CAPC3225X135 | Capacitor - Generic
C26 | 1uF | C_CHIP-1210(3225-METRIC) | CAPC3225X135 | Capacitor - Generic
C27 | 10uF | C_CHIP-1210(3225-METRIC) | CAPC3225X135 | Capacitor - Generic
C28 | 1uF | C_CHIP-1210(3225-METRIC) | CAPC3225X135 | Capacitor - Generic
C29 | 10uF | C_CHIP-1210(3225-METRIC) | CAPC3225X135 | Capacitor - Generic
C30 | 47uF | C-POL_TANTALUM-1206(3216-METRIC) | CAPMP3216X180N | Capacitor Polarised - Generic
C33 | 1uF | C_CHIP-1210(3225-METRIC) | CAPC3225X135 | Capacitor - Generic
D1 | SS34-CHAN | SS34-CHAN | M1-CHAN | SMD Schottky
D2 | M1-CHAN | M1-CHAN | M1-CHAN | SMD Rectifier
D3 | 2PLCC-LED | 2PLCC-LED | LEDC3528X190N | SMD LED
D4 | 2PLCC-LED | 2PLCC-LED | LEDC3528X190N | SMD LED
D5 | LTST-C171GKT | LTST-C171GKT | LED-0805-N-MARK_-_LEDC2012X80N | sub {
ICSP-J | PINHD-2X3 | PINHD-2X3 | 2X03 | PIN HEADER
J1 | B4B-XH-A | B4B-XH-A | JST-XH-4
J2 | MOLEX-4 | MOLEX-4 | MOLEX-4
J3 | MOLEX-4 | MOLEX-4 | MOLEX-4
J4 | MOLEX-6MNT | MOLEX-6MNT | MOLEX-6-MNT
J5 | B2B-XH-A-REV2 | B2B-XH-A-REV2 | JST-XH-2
JP1 | PINHD-1X6/90 | PINHD-1X6/90 | 1X06/90 | PIN HEADER
L1 | SLF10145 | SLF10145 | SLF10145
MP1 | STANDOFF_F/F_M2.5_10MM | STANDOFF_F/F_M2.5_10MM | STANDOFF_HEX_FEMALE_500X1000_M2.5X0.45_MTGP755H270 | Female-Female Standoff/Spacer with Mounting pad and hole.
MP2 | STANDOFF_F/F_M2.5_10MM | STANDOFF_F/F_M2.5_10MM | STANDOFF_HEX_FEMALE_500X1000_M2.5X0.45_MTGP755H270 | Female-Female Standoff/Spacer with Mounting pad and hole.
MP3 | STANDOFF_F/F_M2.5_10MM | STANDOFF_F/F_M2.5_10MM | STANDOFF_HEX_FEMALE_500X1000_M2.5X0.45_MTGP755H270 | Female-Female Standoff/Spacer with Mounting pad and hole.
MP4 | STANDOFF_F/F_M2.5_10MM | STANDOFF_F/F_M2.5_10MM | STANDOFF_HEX_FEMALE_500X1000_M2.5X0.45_MTGP755H270 | Female-Female Standoff/Spacer with Mounting pad and hole.
P1 | 3296W | 3296W | 3296W
Q1 | CSD19533KCS-HORZ | CSD19533KCS-HORZ | TO-220-HORZ | N-Ch Power MOSFET
Q2 | 2N2222TO92-3 | 2N2222TO92-3 | TO92-3 | NPN Amp Trans
Q3 | SSM3K361R-LF | SSM3K361R-LF | SOT-23-F_-_SOTFL95P240X88-3N | N-Ch Switching MOSFET
Q4 | SSM3K361R-LF | SSM3K361R-LF | SOT-23-F_-_SOTFL95P240X88-3N | N-Ch Switching MOSFET
R1 | 1.75K | R-US_CHIP-1206(3216-METRIC) | RESC3216X70 | Resistor Fixed - ANSI
R2 | 7.5K | R-US_CHIP-1206(3216-METRIC) | RESC3216X70 | Resistor Fixed - ANSI
R3 | 1.2K | R-US_CHIP-0805(2012-METRIC) | RESC2012X65 | Resistor Fixed - ANSI
R4 | 2K | R-US_CHIP-0805(2012-METRIC) | RESC2012X65 | Resistor Fixed - ANSI
R5 | 10K | R-US_CHIP-1206(3216-METRIC) | RESC3216X70 | Resistor Fixed - ANSI
R6 | 100m | R-US_CHIP-2512(6332-METRIC) | RESC6332X71 | Resistor Fixed - ANSI
R7 | 1K | R-US_CHIP-1206(3216-METRIC) | RESC3216X70 | Resistor Fixed - ANSI
R8 | 1K | R-US_CHIP-1206(3216-METRIC) | RESC3216X70 | Resistor Fixed - ANSI
R9 | 1K | R-US_CHIP-1206(3216-METRIC) | RESC3216X70 | Resistor Fixed - ANSI
R10 | 1K | R-US_CHIP-1206(3216-METRIC) | RESC3216X70 | Resistor Fixed - ANSI
R11 | 500 | R-US_CHIP-1206(3216-METRIC) | RESC3216X70 | Resistor Fixed - ANSI
R12 | 1K | R-US_CHIP-1206(3216-METRIC) | RESC3216X70 | Resistor Fixed - ANSI
R13 | 100 | R-US_CHIP-1206(3216-METRIC) | RESC3216X70 | Resistor Fixed - ANSI
R14 | 330 | R-US_CHIP-1206(3216-METRIC) | RESC3216X70 | Resistor Fixed - ANSI
R15 | 1K | R-US_CHIP-1206(3216-METRIC) | RESC3216X70 | Resistor Fixed - ANSI
R16 | 1K | R-US_CHIP-1206(3216-METRIC) | RESC3216X70 | Resistor Fixed - ANSI
R17 | 100K | R-US_CHIP-1206(3216-METRIC) | RESC3216X70 | Resistor Fixed - ANSI
R18 | 1K | R-US_CHIP-1206(3216-METRIC) | RESC3216X70 | Resistor Fixed - ANSI
R19 | 100K | R-US_CHIP-1206(3216-METRIC) | RESC3216X70 | Resistor Fixed - ANSI
R20 | 100 | R-US_CHIP-0805(2012-METRIC) | RESC2012X65 | Resistor Fixed - ANSI
R21 | 10K | R-US_CHIP-0805(2012-METRIC) | RESC2012X65 | Resistor Fixed - ANSI
R22 | 1K | R-US_CHIP-1206(3216-METRIC) | RESC3216X70 | Resistor Fixed - ANSI
R23 | 1K | R-US_CHIP-1206(3216-METRIC) | RESC3216X70 | Resistor Fixed - ANSI
R24 | 1K | R-US_CHIP-1206(3216-METRIC) | RESC3216X70 | Resistor Fixed - ANSI
R25 | 10K | R-US_CHIP-1206(3216-METRIC) | RESC3216X70 | Resistor Fixed - ANSI
R26 | 6.1K | R-US_CHIP-1206(3216-METRIC) | RESC3216X70 | Resistor Fixed - ANSI
R27 | 1K | R-US_CHIP-1206(3216-METRIC) | RESC3216X70 | Resistor Fixed - ANSI
RS1 | 14AFR010E | 14AFR010E | RESAD2182W66L1845D630B | High Power Shunt Resistor
RST-SW | B3F-1000 | B3F-1000 | B3F-10-SERIES
U1 | LM22673SOIC-8 | LM22673SOIC-8 | SOIC127P600X170-9T271X340N | 42V 3A Switching Voltage Regutator
U2 | LM358TSSOP | LM358TSSOP | TSSOP-8_-_SOP65P640X120-8N | .ds {
U3 | ATMEGA328PNORM | ATMEGA328PNORM | QFP-32-GP_-_QFP80P900X900X120-33T500N | Stand Alone - Arduino Nano
U4 | INA181A-X | INA181A-X | SOT-23-6PIN | Single Current Shunt Amplifier
U5 | INA181A-X | INA181A-X | SOT-23-6PIN | Single Current Shunt Amplifier
U6 | LM358TSSOP | LM358TSSOP | TSSOP-8_-_SOP65P640X120-8N | .ds {
U7 | LM393 | LM393 | SOIC-8_-_SOIC127P600X175-8N
VR1 | LM317-1.5A-LIN-REG | LM317-1.5A-LIN-REG | SOT230P700X170-4N | Linear Voltage Regulator
VR2 | TL1431TO-92 | TL1431TO-92 | TO-92 | Precision Adjustable Voltage Reference
VR3 | LM317 | LM317 | SOT230P700X170-4N | Linear Voltage Regulator
X3 | 5566-2 | 5566-2 | 5566-2 | Mini FIT connector 2 pol
XTAL1 | HC-49USX | HC-49USX | XTALRR488W43L1097T455H350B | Quartz Oscillator

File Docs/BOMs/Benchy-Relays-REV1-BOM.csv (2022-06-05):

Part | Value | Device | Package | Description
C1 | 100nF | C_CHIP-1210(3225-METRIC) | CAPC3225X135 | Capacitor - Generic
C2 | 100nF | C_CHIP-1210(3225-METRIC) | CAPC3225X135 | Capacitor - Generic
C3 | 4.7uF | C_CHIP-1210(3225-METRIC) | CAPC3225X135 | Capacitor - Generic
D1 | S1M-CHAN | S1M-CHAN | S1M-CHAN | SMD Rectifier
D2 | S1M-CHAN | S1M-CHAN | S1M-CHAN | SMD Rectifier
D3 | S1M-CHAN | S1M-CHAN | S1M-CHAN | SMD Rectifier
D4 | S1M-CHAN | S1M-CHAN | S1M-CHAN | SMD Rectifier
D5 | S1M-CHAN | S1M-CHAN | S1M-CHAN | SMD Rectifier
D6 | S1M-CHAN | S1M-CHAN | S1M-CHAN | SMD Rectifier
D7 | S1M-CHAN | S1M-CHAN | S1M-CHAN | SMD Rectifier
D8 | S1M-CHAN | S1M-CHAN | S1M-CHAN | SMD Rectifier
J-COMMS | B4B-XH-A-REV2 | B4B-XH-A-REV2 | JST-XH-4
J-OUT-1 | B2B-XH-A-REV2 | B2B-XH-A-REV2 | JST-XH-2
J-OUT-2 | B2B-XH-A-REV2 | B2B-XH-A-REV2 | JST-XH-2
J-OUT-3 | B2B-XH-A-REV2 | B2B-XH-A-REV2 | JST-XH-2
J-OUT-4 | B2B-XH-A-REV2 | B2B-XH-A-REV2 | JST-XH-2
J-OUT-5 | B2B-XH-A-REV2 | B2B-XH-A-REV2 | JST-XH-2
J-OUT-6 | B2B-XH-A-REV2 | B2B-XH-A-REV2 | JST-XH-2
J-OUT-7 | B2B-XH-A-REV2 | B2B-XH-A-REV2 | JST-XH-2
J-OUT-8 | B2B-XH-A-REV2 | B2B-XH-A-REV2 | JST-XH-2
J-PWR | B2B-XH-A-REV2 | B2B-XH-A-REV2 | JST-XH-2
MP1 | STANDOFF_F/F_M3_10MM | STANDOFF_F/F_M3_10MM | STANDOFF_HEX_FEMALE_550X1000_M3X0.5_MTGP850H320 | Female-Female Standoff/Spacer with Mounting pad and hole.
MP2 | STANDOFF_F/F_M3_10MM | STANDOFF_F/F_M3_10MM | STANDOFF_HEX_FEMALE_550X1000_M3X0.5_MTGP850H320 | Female-Female Standoff/Spacer with Mounting pad and hole.
MP3 | STANDOFF_F/F_M3_10MM | STANDOFF_F/F_M3_10MM | STANDOFF_HEX_FEMALE_550X1000_M3X0.5_MTGP850H320 | Female-Female Standoff/Spacer with Mounting pad and hole.
MP4 | STANDOFF_F/F_M3_10MM | STANDOFF_F/F_M3_10MM | STANDOFF_HEX_FEMALE_550X1000_M3X0.5_MTGP850H320 | Female-Female Standoff/Spacer with Mounting pad and hole.
Q1 | SQ2310ES | SQ2310ES | SOT-23-3_-_SOT95P280X100-3N | N-Ch MOSFET
Q2 | SQ2310ES | SQ2310ES | SOT-23-3_-_SOT95P280X100-3N | N-Ch MOSFET
Q3 | SQ2310ES | SQ2310ES | SOT-23-3_-_SOT95P280X100-3N | N-Ch MOSFET
Q4 | SQ2310ES | SQ2310ES | SOT-23-3_-_SOT95P280X100-3N | N-Ch MOSFET
Q5 | SQ2310ES | SQ2310ES | SOT-23-3_-_SOT95P280X100-3N | N-Ch MOSFET
Q6 | SQ2310ES | SQ2310ES | SOT-23-3_-_SOT95P280X100-3N | N-Ch MOSFET
Q7 | SQ2310ES | SQ2310ES | SOT-23-3_-_SOT95P280X100-3N | N-Ch MOSFET
Q8 | SQ2310ES | SQ2310ES | SOT-23-3_-_SOT95P280X100-3N | N-Ch MOSFET
R1 | 10K | R-US_CHIP-0805(2012-METRIC) | RESC2012X65 | Resistor Fixed - ANSI
R2 | 100 | R-US_CHIP-0805(2012-METRIC) | RESC2012X65 | Resistor Fixed - ANSI
R3 | 100 | R-US_CHIP-0805(2012-METRIC) | RESC2012X65 | Resistor Fixed - ANSI
R4 | 100 | R-US_CHIP-0805(2012-METRIC) | RESC2012X65 | Resistor Fixed - ANSI
R5 | 100 | R-US_CHIP-0805(2012-METRIC) | RESC2012X65 | Resistor Fixed - ANSI
R6 | 100 | R-US_CHIP-0805(2012-METRIC) | RESC2012X65 | Resistor Fixed - ANSI
R7 | 100 | R-US_CHIP-0805(2012-METRIC) | RESC2012X65 | Resistor Fixed - ANSI
R8 | 100 | R-US_CHIP-0805(2012-METRIC) | RESC2012X65 | Resistor Fixed - ANSI
R9 | 100 | R-US_CHIP-0805(2012-METRIC) | RESC2012X65 | Resistor Fixed - ANSI
R10 | 10K | R-US_CHIP-0805(2012-METRIC) | RESC2012X65 | Resistor Fixed - ANSI
R11 | 10K | R-US_CHIP-0805(2012-METRIC) | RESC2012X65 | Resistor Fixed - ANSI
R12 | 10K | R-US_CHIP-0805(2012-METRIC) | RESC2012X65 | Resistor Fixed - ANSI
R13 | 10K | R-US_CHIP-0805(2012-METRIC) | RESC2012X65 | Resistor Fixed - ANSI
R14 | 10K | R-US_CHIP-0805(2012-METRIC) | RESC2012X65 | Resistor Fixed - ANSI
R15 | 10K | R-US_CHIP-0805(2012-METRIC) | RESC2012X65 | Resistor Fixed - ANSI
R16 | 10K | R-US_CHIP-0805(2012-METRIC) | RESC2012X65 | Resistor Fixed - ANSI
R17 | 10K | R-US_CHIP-0805(2012-METRIC) | RESC2012X65 | Resistor Fixed - ANSI
RL1 | ALQ112 | ALQ112 | ALQ112 | General Relay
RL2 | ALQ112 | ALQ112 | ALQ112 | General Relay
RL3 | ALQ112 | ALQ112 | ALQ112 | General Relay
RL4 | ALQ112 | ALQ112 | ALQ112 | General Relay
RL5 | ALQ112 | ALQ112 | ALQ112 | General Relay
RL6 | ALQ112 | ALQ112 | ALQ112 | General Relay
RL7 | ALQ112 | ALQ112 | ALQ112 | General Relay
RL8 | ALQ112 | ALQ112 | ALQ112 | General Relay
U1 | PCF8574APWRTSSOP-20 | PCF8574APWRTSSOP-20 | SOP65P640X120-20N | 8-Bit IO Expander

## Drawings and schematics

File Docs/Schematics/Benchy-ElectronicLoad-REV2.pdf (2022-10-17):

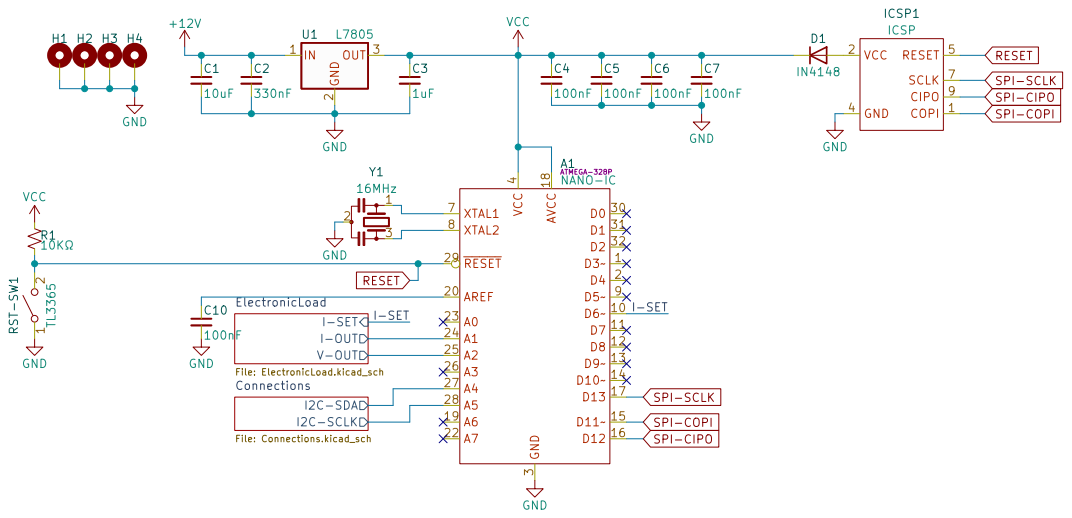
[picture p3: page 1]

1 2 RST-SW1 TL3365 D3~1 D6~10 D7 11 D8 12 D9~13 D10~14 D11~15 D12 16 D13 17 AVCC 18 A6 19 D4 2 AREF 20 A7 22 A0 23 A1 24 A2 25 A3 26 A4 27 A5 28 ~{RESET} 29 GND
16MHz VCC

File: Benchy-ElectronicLoad-REV1.kicad_sch Sheet: /
Id: 1/3 Title:

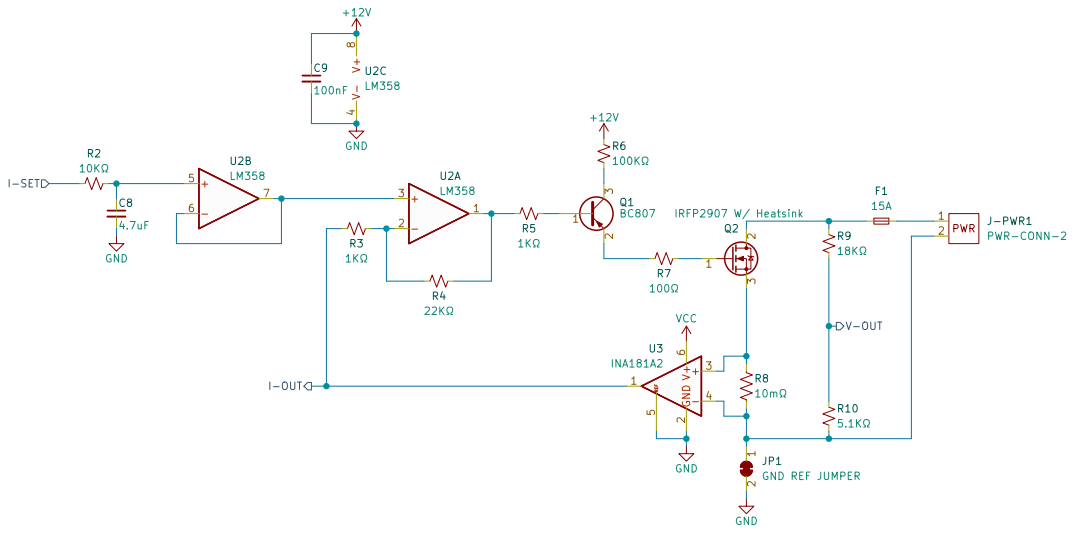
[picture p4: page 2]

File: ElectronicLoad.kicad_sch Sheet: /ElectronicLoad/
Id: 2/3 Title:

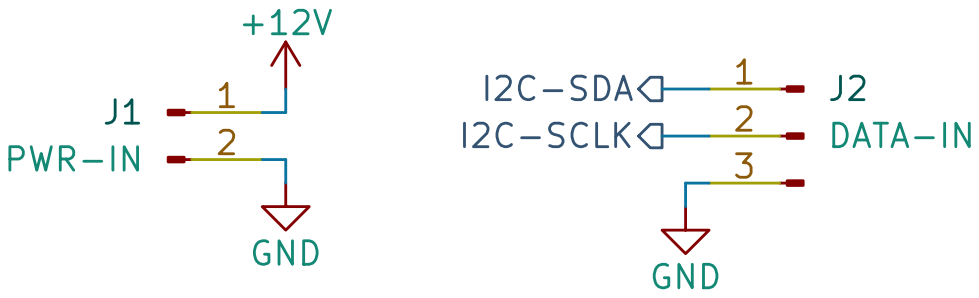
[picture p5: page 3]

File: Connections.kicad_sch Sheet: /Connections/
Id: 3/3 Title:

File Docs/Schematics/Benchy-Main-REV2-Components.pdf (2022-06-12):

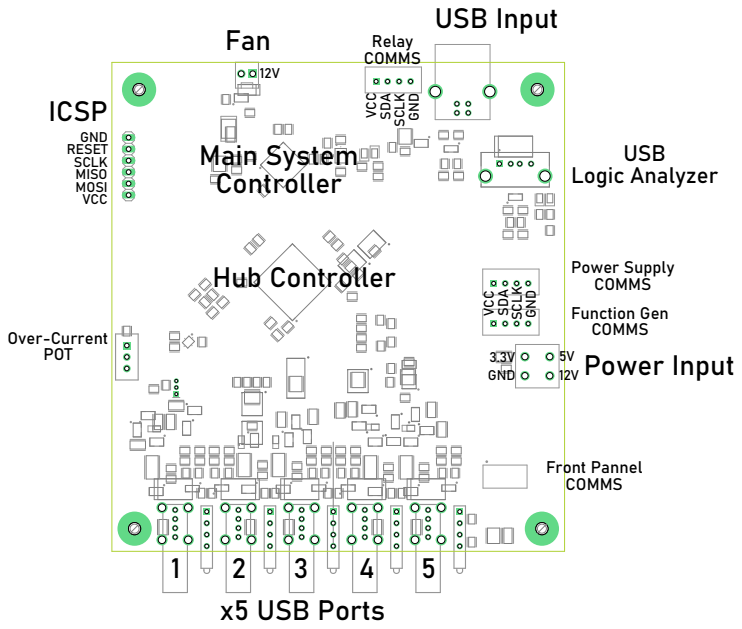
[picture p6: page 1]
Fan; USB Input; ICSP; Over-Current POT; USB Logic Analyzer; Power Input; Power Supply COMMS Function Gen COMMS; Relay COMMS; x5 USB Ports; Front Pannel COMMS; Hub Controller; Main System Controller; GND; VCC; RESET SCLK MISO MOSI

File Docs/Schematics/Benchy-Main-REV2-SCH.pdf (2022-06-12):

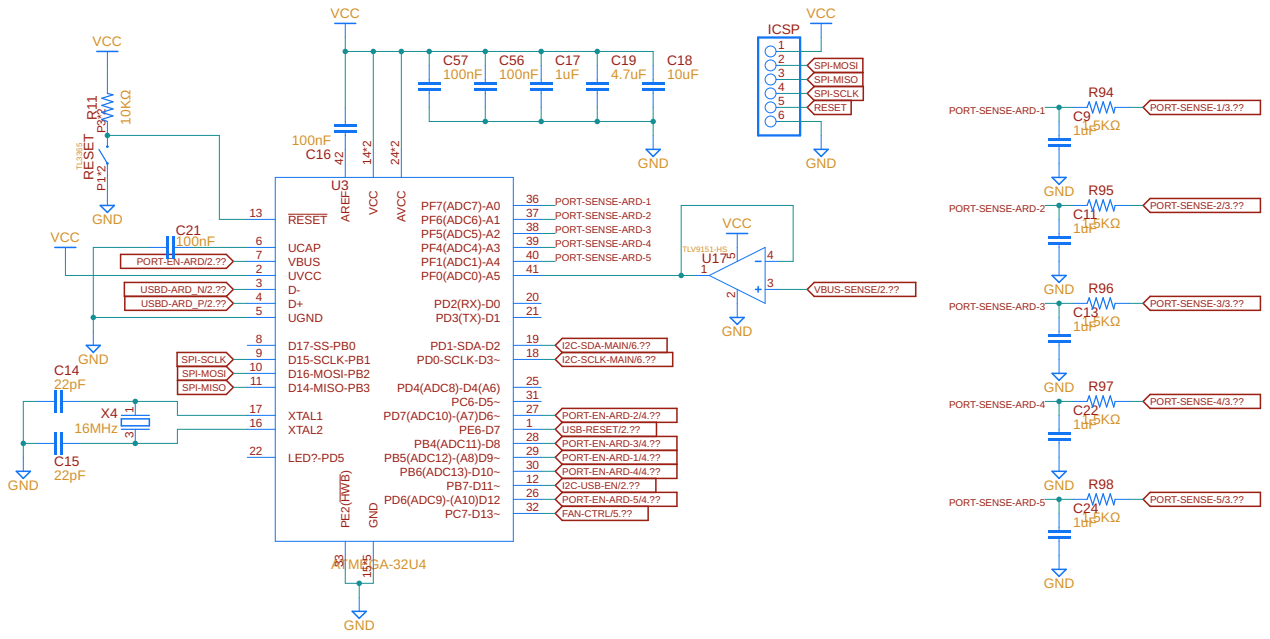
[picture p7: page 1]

GND GND GND GND GND

VBUS-SENSE/2.?? PORT-EN-ARD/2.??

I2C-USB-EN/2.?? USB-RESET/2.?? PORT-EN-ARD-3/4.?? PORT-EN-ARD-2/4.??

PORT-EN-ARD-1/4.?? PORT-EN-ARD-4/4.?? FAN-CTRL/5.??

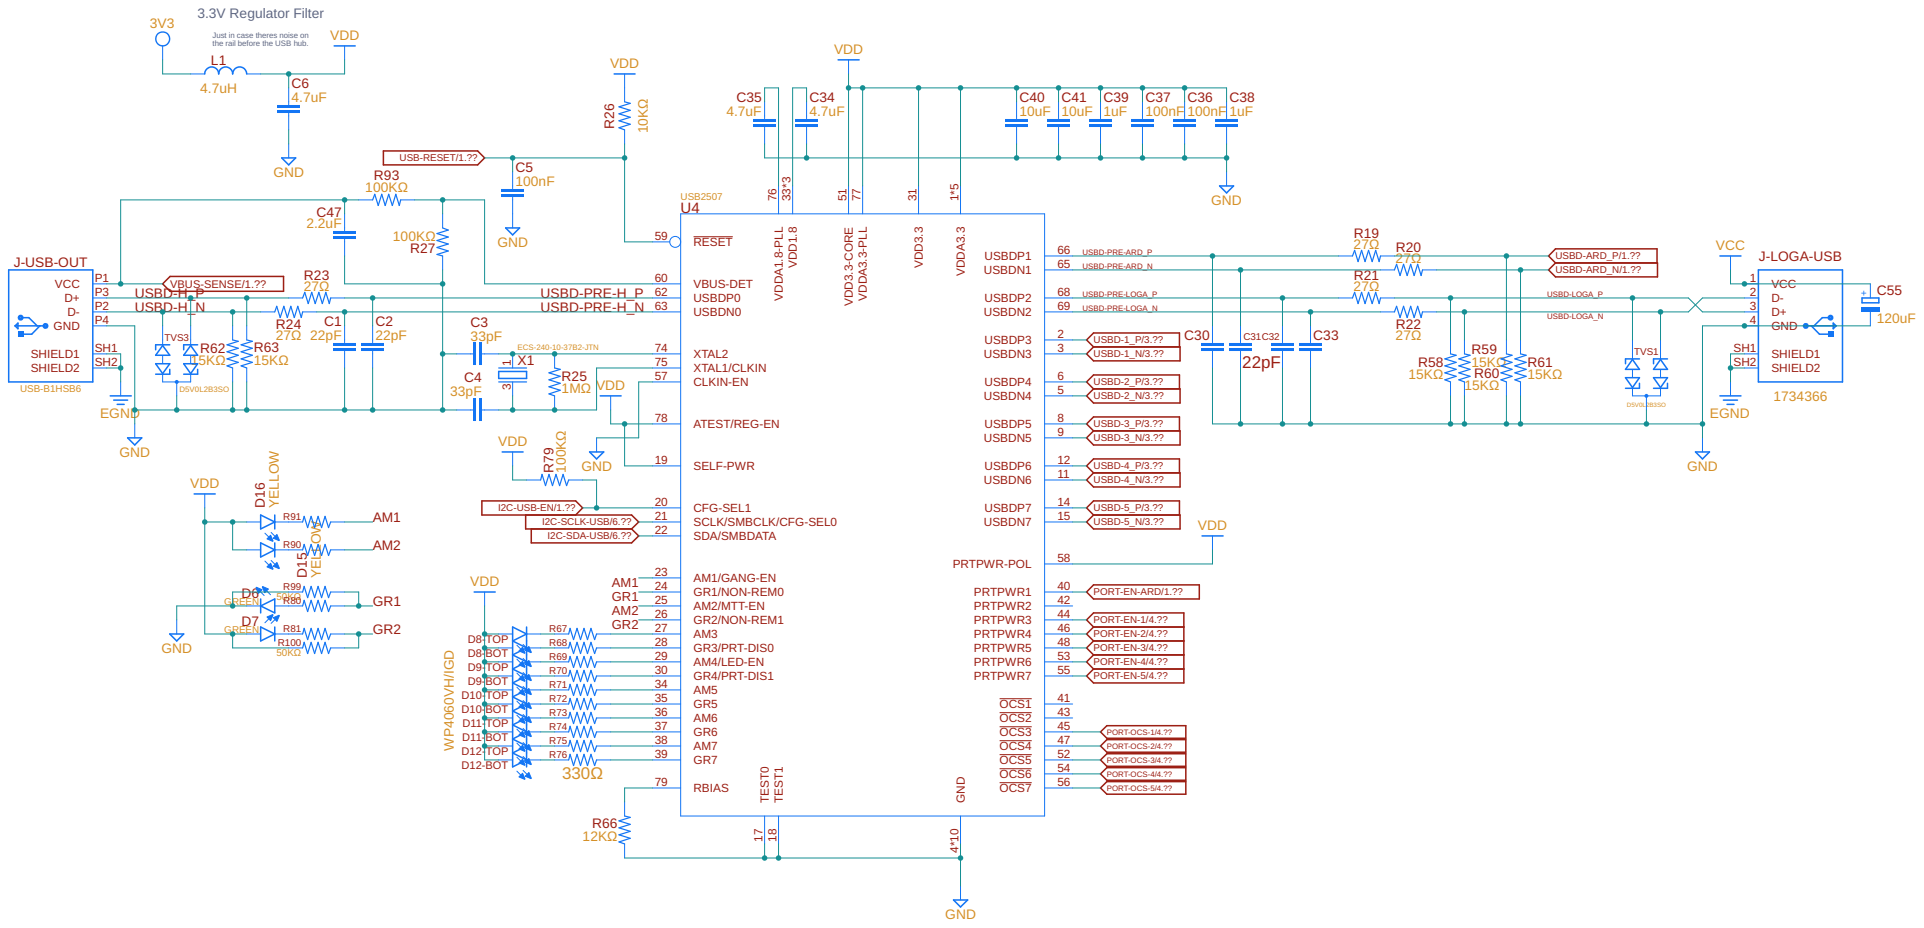
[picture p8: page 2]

Just in case theres noise on
the rail before the USB hub.

1*5 USBDP3
USBD-PRE-LOGA_P USBD-PRE-LOGA_N USBD-1_P/3.?? USBD-1_N/3.?? USBD-2_N/3.?? USBD-3_P/3.?? USBD-4_P/3.?? USBD-4_N/3.?? USBD-5_P/3.?? USBD-5_N/3.??

USBD-PRE-ARD_P USBD-PRE-ARD_N

VDD
D8-BOT D9-TOP D9-BOT D10-TOP D10-BOT D11-TOP D11-BOT D12-TOP D12-BOT
12KΩ WP4060VH/IGD

PORT-EN-ARD/1.?? PORT-EN-1/4.?? PORT-EN-2/4.?? PORT-EN-3/4.?? PORT-EN-4/4.?? PORT-EN-5/4.??

PORT-OCS-1/4.?? PORT-OCS-2/4.?? PORT-OCS-3/4.?? PORT-OCS-4/4.?? PORT-OCS-5/4.??

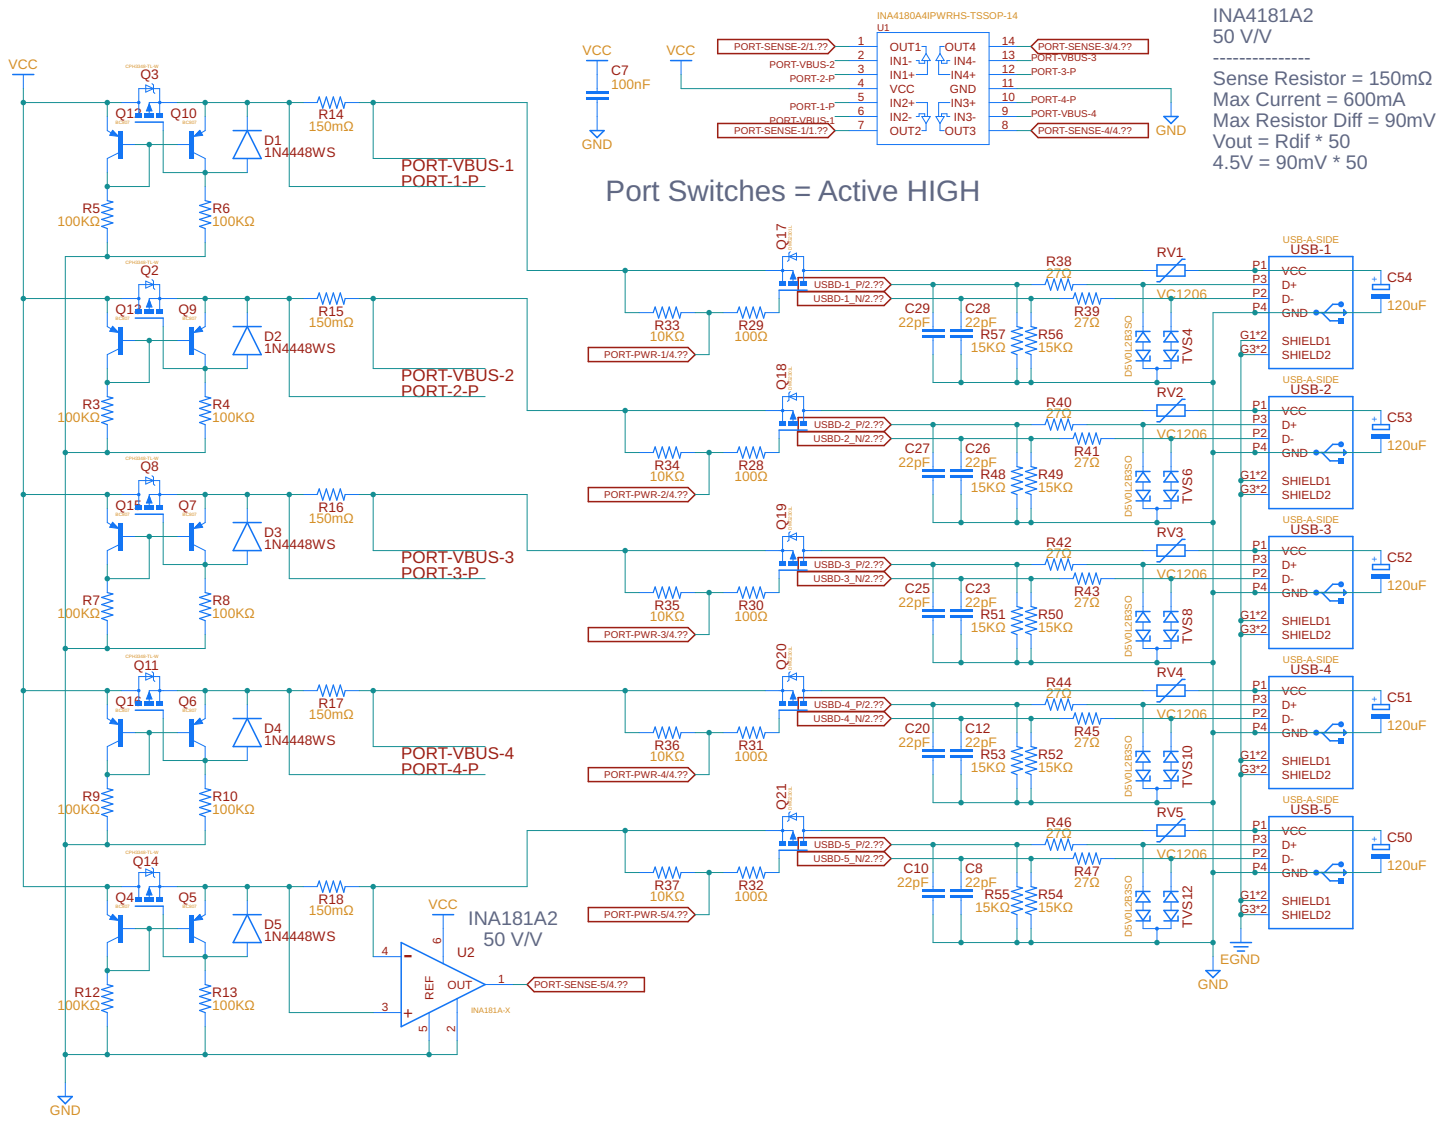
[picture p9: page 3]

Port Switches = Active HIGH

P1 | D- P2 D+ P3 GND

P4 | SHIELD1 G1*2 SHIELD2 G3*2

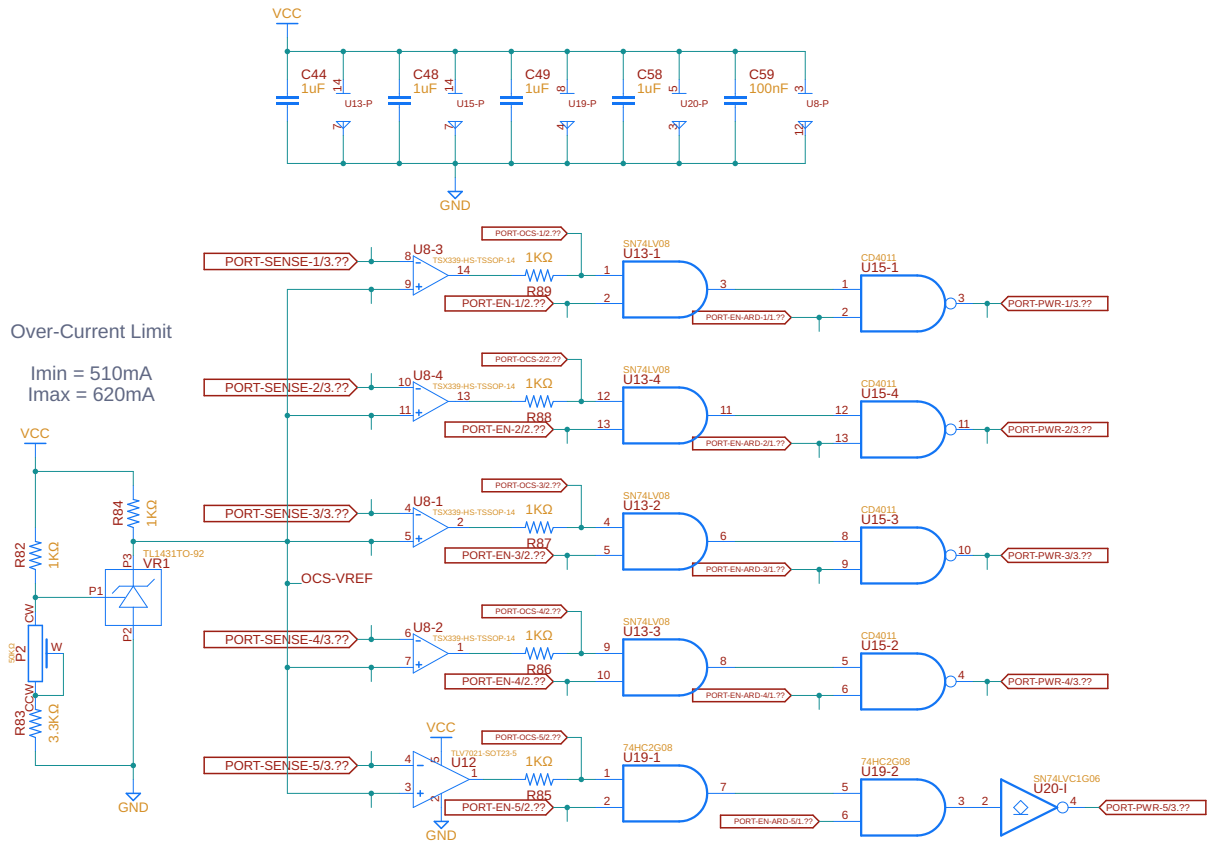
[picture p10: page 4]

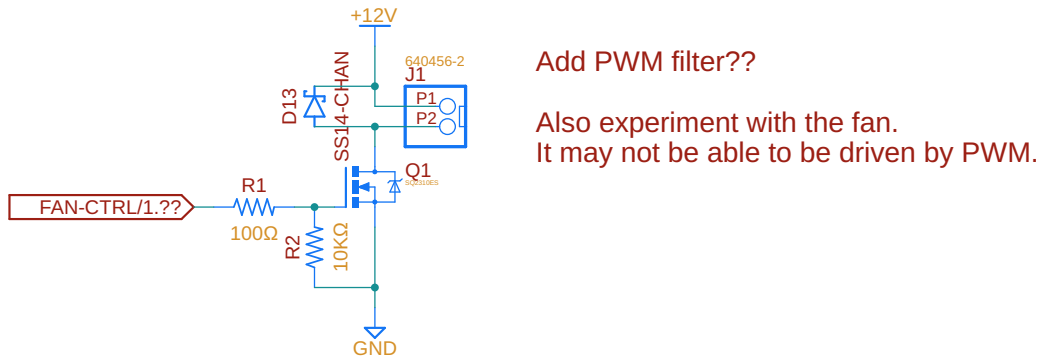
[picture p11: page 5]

Also experiment with the fan.

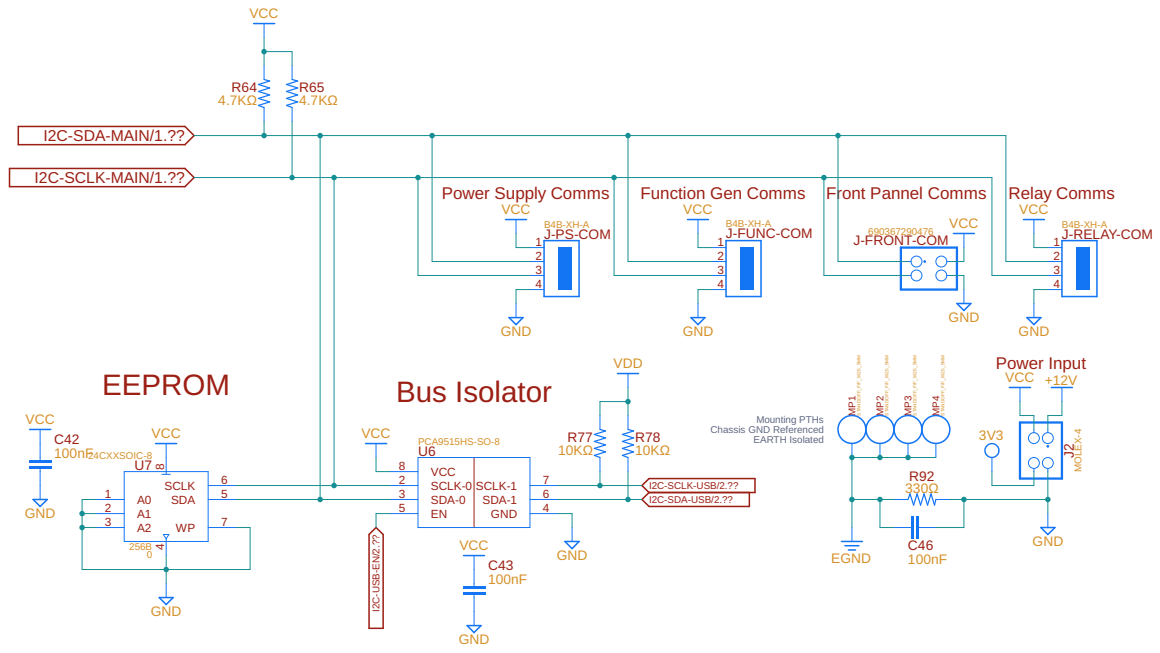
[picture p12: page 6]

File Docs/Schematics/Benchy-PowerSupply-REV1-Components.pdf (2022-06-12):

## ICSP

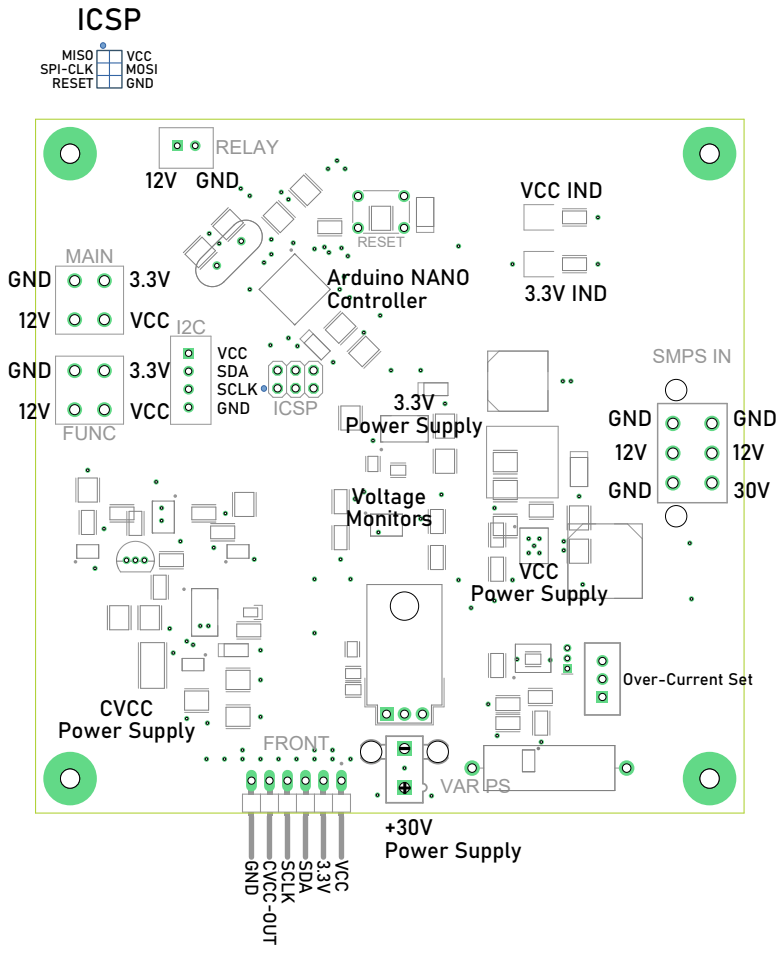
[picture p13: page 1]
RELAY; MAIN; FUNC; FRONT; VAR PS; SMPS IN; RESET; ICSP; VCC IND; 3.3V IND 3.3V; VCC; GND; VCC SDA SCLK GND; GND 12V; 12V GND; +30V Power Supply; VCC Power Supply; 3.3V Power Supply; Voltage Monitors; CVCC Power Supply; Arduino NANO Controller; VCC MOSI; MISO; SPI-CLK

Over-Current Set

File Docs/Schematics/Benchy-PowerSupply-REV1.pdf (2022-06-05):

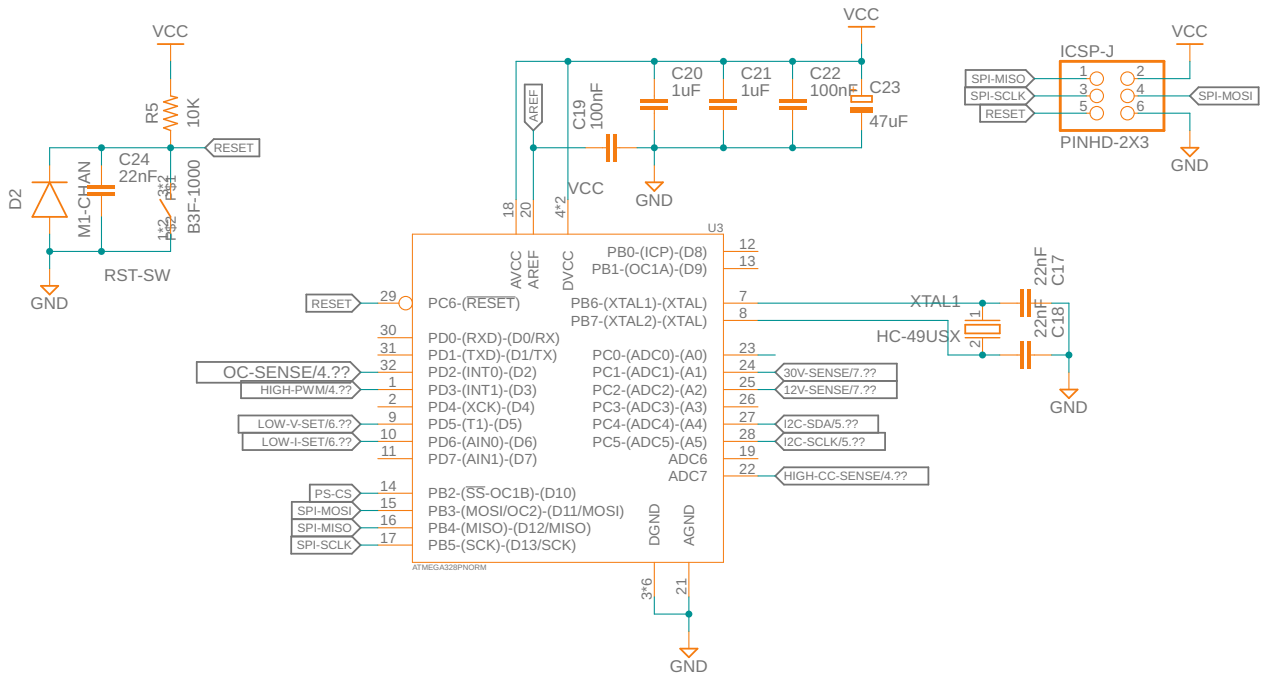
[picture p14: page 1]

LOW-I-SET/6.?? HIGH-PWM/4.?? OC-SENSE/4.??

LOW-V-SET/6.?? PS-CS






https://www.youtube.com/watch?v=CIGjActDeoM&list=PLBF35875F73B5C9B5&index=1







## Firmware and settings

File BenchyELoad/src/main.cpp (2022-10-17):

#include <Arduino.h>
#include <Wire.h>
#include "Benchy-ElectronicLoad-REV2Pinout.h"

// I2C Interface

// Receive:
//   0x0 Reset
//   0x1 Current Set - 2 bytes
//   0x2 Power Set   - 2 bytes

// Request:
//   0x0 Load Monitors - 4 bytes
//   0x1 Set Value     - 1 byte
//   0x2 Status        - 1 byte

namespace LoadConstants
{
  const uint8_t ADDR = 0x21;
  const int MAX_LOAD_AMP = 10;
  const int MAX_LOAD_VOLT = 30;
  const int MAX_LOAD_PWR = MAX_LOAD_AMP * MAX_LOAD_VOLT;

  // Load voltage resistor ratio
  // TOP: 18K
  // BOT: 5.1K
  const float VOLT_DIV_RATIO = 0.2833333333;

  const float VCC = 4.98;
} // namespace LoadConstants

enum LimitMode
{
  OFF = 0,
  CURRENT_SET = 0b01,
  POWER_SET = 0b10,
  LOWEST_SET = 0b11,
} limit;

union FloatConverter
{
  uint8_t buffer[4];
  float data;
} loadCurrent, loadVoltage, loadISet, loadPSet;

// Raw Current Amp
uint16_t i_input = 0;
uint16_t v_input = 0;

uint8_t iSet = 0;
uint8_t pSet = 0;

uint8_t setPoint = 0;

uint8_t buffer[8] = { };

bool loadActive = false;
bool overVolt = false;
bool overCurr = false;
bool overPower = false;

volatile int command = 0;

void SoftReset()
{
  i_input = 0;
  v_input = 0;
  iSet = 0;

  loadActive = false;
  overVolt = false;
  overCurr = false;
  overPower = false;
}

int ConcatBytes(uint8_t upper, uint8_t lower)
{
  return lower | (upper << 8);
}

void ReadInputs()
{
  i_input = analogRead(Anlg::SensePins::I_PIN);
  v_input = analogRead(Anlg::SensePins::V_PIN);
}

void ClampSetPoint()
{
  if (loadISet.data > LoadConstants::MAX_LOAD_AMP)
  {
    loadISet.data = LoadConstants::MAX_LOAD_AMP;
  }
  if (loadPSet.data > LoadConstants::MAX_LOAD_PWR)
  {
    loadPSet.data = LoadConstants::MAX_LOAD_PWR;
  }
}

void CalcSetPoint()
{
  if (loadActive)
  {
    iSet = (loadISet.data / LoadConstants::MAX_LOAD_AMP) * 255;
    pSet = (loadPSet.data / LoadConstants::MAX_LOAD_PWR) * 255;
    if (limit == LimitMode::CURRENT_SET)
    {
      setPoint = iSet;
    }
    else if (limit == LimitMode::POWER_SET)
    {
      setPoint = pSet;
    }
    else if (limit == LimitMode::LOWEST_SET)
    {
      if (iSet < pSet)
      {
        setPoint = iSet;
      }
      else
      {
        setPoint = pSet;
      }
    }
  }
  else
  {
    setPoint = 0;
  }
  analogWrite(Digitl::SetPins::I_PIN, setPoint);
}

void CalcCurrent()
{
  loadCurrent.data = (i_input * (LoadConstants::VCC / 1023.0)) * 2;
}

// Calculate the voltage from the ADC conversion;
void CalcVoltage()
{
  // loadVoltage.data = (v_input * (LoadConstants::VCC / 1023.0)) * LoadConstants::VOLT_DIV_RATIO;
  loadVoltage.data = v_input / 1023.0 * LoadConstants::MAX_LOAD_VOLT;
}

// Checks inputs for values beyond the capacity of the circuit.
void LimitCheck()
{
  loadActive = true;
  if (loadVoltage.data > LoadConstants::MAX_LOAD_VOLT)
  {
    loadActive = false;
    overVolt = true;
  }
  else
  {
    overVolt = false;
  }
  
  if (loadCurrent.data > LoadConstants::MAX_LOAD_AMP)
  {
    loadActive = false;
    overCurr = true;
  }
  else
  {
    overCurr = false;
  }

  if (loadCurrent.data * loadVoltage.data > LoadConstants::MAX_LOAD_PWR)
  {
    loadActive = false;
    overPower = true;
  }
  else
  {
    overPower = false;
  }
}

// Not sure if this method will work...
void Receive(int len)
{
  if (len > 0)
  {
    command = Wire.read();

    if (command == 0x0)
    {
      SoftReset();
    }
    else if (command == 0x1)
    {
      Wire.readBytes(loadISet.buffer, 4);
    }
    else if (command == 0x2)
    {
      Wire.readBytes(loadPSet.buffer, 4);
      if (loadPSet.data >= LoadConstants::MAX_LOAD_PWR)
      {
        loadPSet.data = LoadConstants::MAX_LOAD_PWR;
      }
      iSet = ((loadPSet.data * (LoadConstants::VCC / 1023.0)) / loadVoltage.data) / LoadConstants::MAX_LOAD_AMP / 255;
    }
  }
}

void Request()
{
  if (command == 0x10)
  {
    buffer[0] = i_input & 0xFF;
    buffer[1] = i_input >> 8;
    buffer[2] = v_input & 0xFF;
    buffer[3] = v_input >> 8;

    Wire.write(buffer, 4);
  }
  else if (command == 0x11)
  {
    Wire.write(iSet);
  }
  else if (command == 0x12)
  {
    buffer[0] = (uint8_t)overCurr;
    buffer[0] |= ((uint8_t)overPower << 1);
    buffer[0] |= ((uint8_t)overVolt << 2);
    buffer[0] |= ((uint8_t)loadActive << 3);
    buffer[0] |= ((uint8_t)limit << 4);

    Wire.write(buffer[0]);
  }
}

void setup()
{
  Wire.begin(LoadConstants::ADDR);

  Wire.onReceive(Receive);
  Wire.onRequest(Request);
}

void loop()
{
  ReadInputs();
  CalcCurrent();
  CalcVoltage();
  LimitCheck();
  ClampSetPoint();
  CalcSetPoint();
}

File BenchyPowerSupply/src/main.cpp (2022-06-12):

#include <Arduino.h>
#include <Wire.h>
#include "BenchyPowerSupplyREV2Pinout.h"
#include "IntConverter.h"

#define recieveBufferSize 16
#define sendBufferSize 8

#define V12DividerRatio 0.33
#define V30DividerRatio 0.091

const int FRONT_ADDR = 0x12;
const int address = 0x11;

uint8_t receiveBuffer[recieveBufferSize] = {};
uint8_t sendBuffer[sendBufferSize] = {};
uint8_t receiveCommand = 0;
uint8_t sendCommand = 0;
uint8_t readSelect = 0;

uint8_t lowSetVoltage = 0;
uint8_t lowSetCurrent = 0;

uint8_t highSet = 0;

uint16_t V30Sense = 0;
uint16_t V12Sense = 0;
uint16_t highPSCurrent = 0;
uint16_t highPSVoltage = 0;
uint16_t lowPSCurrent = 0;
uint16_t lowPSVoltage = 0;

bool overCurrent = false;

bool lowPSEnable = false;
bool highPSEnable = false;

// uint8_t GetLowByte(uint16_t value)
// {
//   return value & 0xFF;
// }

// uint8_t GetHighByte(uint16_t value)
// {
//   return (value & 0xFF00) >> 8;
// }

void HandleOverCurrent()
{
  overCurrent = true;
  highSet = 0;
}

void InitPins()
{
  attachInterrupt(
    digitalPinToInterrupt(Digitl::PowerPins::OC_SENSE_INT_PIN),
    HandleOverCurrent,
    RISING
  );
}

#pragma region Main Controller Command functions
void ResetCMD()
{
  lowPSEnable = false;
  highPSEnable = false;
  lowSetVoltage = 0;
  lowSetCurrent = 0;
  highSet = 0;
}

void LowPSSetVoltageCMD()
{
  lowSetVoltage = receiveBuffer[1];
}

void LowPSSetCurrentCMD()
{
  lowSetCurrent = receiveBuffer[1];
}

void HighPSSetVoltageCMD()
{
  highSet = receiveBuffer[1];
}

void SetPSStatesCMD()
{
  uint8_t val = receiveBuffer[1];
  lowPSEnable = val & 0b01;
  highPSEnable = val & 0b10;
}

void SetReadRegisterCMD()
{
  readSelect = receiveBuffer[1];
}

int PSMonitorCMD()
{
  sendBuffer[8] = {};
  sendBuffer[0] = GetLowByte(lowPSCurrent);
  sendBuffer[1] = GetHighByte(lowPSCurrent);
  sendBuffer[2] = GetLowByte(lowPSVoltage);
  sendBuffer[3] = GetHighByte(lowPSVoltage);
  sendBuffer[4] = GetLowByte(highPSCurrent);
  sendBuffer[5] = GetHighByte(highPSCurrent);
  sendBuffer[6] = GetLowByte(highPSVoltage);
  sendBuffer[7] = GetHighByte(highPSVoltage);
  
  return 8;
}

int PowerRailMonitorCMD()
{
  sendBuffer[4] = {};
  sendBuffer[0] = GetLowByte(V30Sense);
  sendBuffer[1] = GetHighByte(V30Sense);
  sendBuffer[2] = GetLowByte(V12Sense);
  sendBuffer[3] = GetHighByte(V12Sense);
  return 4;
}

int StatusCMD()
{
  sendBuffer[1] = {};
  uint8_t value = overCurrent;
  value <<= 1;
  value |= highPSEnable;
  value <<= 1;
  value |= lowPSEnable;
  sendBuffer[0] = value;
  return 1;
}

void (*receiveActions[])() = {
  ResetCMD,
  LowPSSetVoltageCMD,
  LowPSSetCurrentCMD,
  HighPSSetVoltageCMD,
  SetPSStatesCMD,
  SetReadRegisterCMD
};

int (*sendActions[])() = {
  PSMonitorCMD,
  PowerRailMonitorCMD,
  StatusCMD,
};
#pragma endregion

void I2CReceive(int len)
{
  int available = Wire.available();
  for (size_t i = 0; i < available; i++)
  {
    receiveBuffer[i] = Wire.read();
  }
  // Wire.readBytes(receiveBuffer, len);
  receiveCommand = receiveBuffer[0];
  receiveActions[receiveCommand]();
}

void I2CRequest()
{
  sendBuffer[sendBufferSize] = {};
  int size = sendActions[readSelect]();
  // int size = 0;
  // if (sendCommand == 0) {
  //   size = PSMonitorCMD();
  // }
  // else if (sendCommand == 1) {
  //   size = PowerRailMonitorCMD();
  // }
  // else if (sendCommand == 2) {
  //   size = StatusCMD();
  // }
  Wire.write(sendBuffer, size);
}

#pragma region PS Functions
void AnalogRead()
{
  // Not implemented on REV1
  // Added to REV2
  lowPSCurrent++;
  highPSCurrent = analogRead(Anlg::PowerPins::HIGH_CC_SENSE_PIN);
  V12Sense = analogRead(Anlg::PowerPins::V12_SENSE_PIN);
  V30Sense = analogRead(Anlg::PowerPins::V30_SENSE_PIN);
}

void SetPowerSupplies()
{
  analogWrite(Digitl::PowerPins::LOW_ISET_PIN, lowSetCurrent);
  analogWrite(Digitl::PowerPins::LOW_VSET_PIN, lowSetVoltage);
  analogWrite(Digitl::PowerPins::HIGH_PWM_PIN, highSet);
}
#pragma endregion

void setup()
{
  Wire.begin(address);
  Wire.onReceive(I2CReceive);
  Wire.onRequest(I2CRequest);

  //Initial Testing
  InitPins();
}

void loop()
{
  AnalogRead();
  SetPowerSupplies();
  delay(10);
}

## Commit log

2022-06-05 Initial PS functionality add block diagram
    [BenchHelper-Main-REV2-PCB v77_Legend_Bot.GBO, BenchHelper-Main-REV2-PCB v77_Legend_Top.GTO, BenchHelper-Main-REV2-PCB v77_Paste_Bot.GBP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]
2022-06-12 Add docs and projects
    [Benchy-Main-REV2-BOM.csv]
